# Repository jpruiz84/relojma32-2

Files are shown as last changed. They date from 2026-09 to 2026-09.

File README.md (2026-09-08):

# Reloj MA 32-2 — Electrónica

Repositorio de diseño del **Reloj Multi Alarma MA 32-2** de **Galeras Digital**: un temporizador
programable para timbres escolares construido alrededor de un microcontrolador PIC16F877A.
Contiene el firmware en ensamblador, los esquemáticos y PCB, los planos de la caja metálica,
el manual de usuario, el folleto comercial y los archivos de producción.

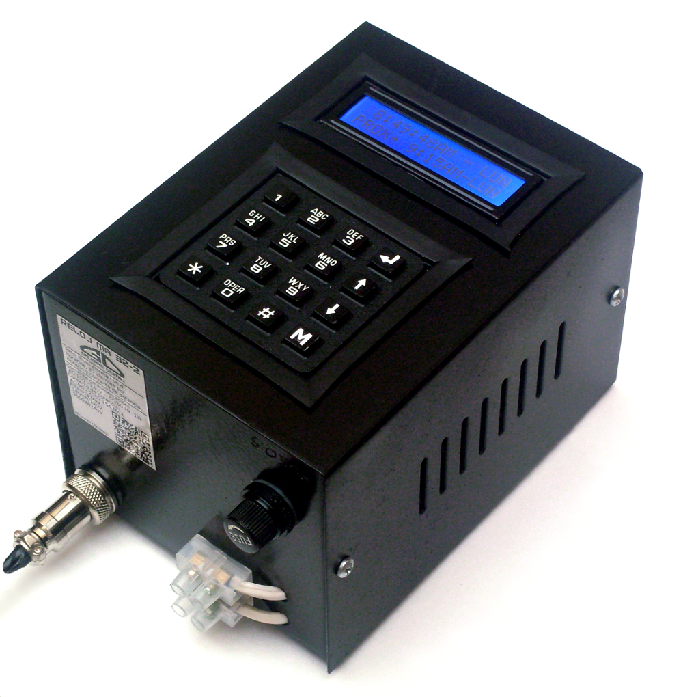
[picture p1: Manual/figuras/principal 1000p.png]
Reloj MA 32-2


## Simulador web 3D

La aplicación en [`simulator/`](simulator/) permite operar el reloj con su teclado original,
programar los cuatro horarios, acelerar el tiempo y retirar la tapa para inspeccionar los
circuitos. Usa el modelo 3D original de ARES, las medidas de la caja, las fotografías y una
implementación funcional basada en el ensamblador.

```bash
cd simulator
npm ci
npm run dev
```

Incluye importación/exportación de EEPROM `.MCH`, protección por contraseña, respaldo de hora,
contacto de potencia, fusible y sonido opcional. Consulte el [README del simulador](simulator/README.md)
y las [notas de fidelidad](simulator/docs/FIDELITY.md) para las fuentes, pruebas, detalles inferidos
y diferencias frente a una emulación del PIC a nivel de instrucciones.

El logotipo del menú LCD reproduce exactamente los 48 bytes de `LCD_DIBLOGORET`: seis
caracteres de 5 × 8 píxeles en las últimas seis posiciones de la primera línea, tanto
en la pantalla 3D como en el panel de controles.

Para generar la versión de producción y ejecutar las pruebas:

```bash
npm run build   # Archivos estáticos en simulator/dist/
npm test       # Pruebas de firmware, EEPROM y bitmap del logotipo
npm run test:e2e # Pruebas de interacción en navegador
```

El [despliegue como servicio](simulator/deploy/README.md) usa HTTPS, renovación automática
del certificado, inicio al arrancar el servidor y acceso mediante un enlace privado
aleatorio. La dirección del servidor y el enlace de acceso se configuran fuera del
repositorio. La guía incluye actualización, reversión y revocación del enlace.

## Descripción del producto

El Reloj MA 32-2 es un dispositivo electrónico con reloj calendario que activa un timbre,
chicharra, alarma u otro equipo similar según un horario programado y durante un tiempo
configurable. Fue diseñado para establecimientos educativos que marcan el cambio de clase con
timbre, de modo que la programación se realiza una sola vez y el equipo se encarga del resto.

Los equipos han estado en funcionamiento en instituciones educativas de la ciudad de Pasto
(Colombia), entre ellas el Colegio Ciudad de Pasto, INEM, Liceo Central de Nariño, Normal
Superior y Heraldo Romero.

### Características principales

| Característica | Detalle |
|---|---|
| Horarios | 4 tipos de horario independientes, asignables a cada día de la semana (o ninguno, OFF) |
| Alarmas | 30 alarmas por horario (120 en total), cada una con estado ON/OFF |
| Tipos de timbrado | 1TC (1 timbre corto), 1TL (1 timbre largo), 2TC (2 cortos), 3TC (3 cortos) |
| Duración de timbres | Duración del timbre corto (TC) y largo (TL) configurables en segundos |
| Contacto de potencia | 15 A máx. a 100–240 VAC (1800 W / 3600 W), protegido con fusible de 15 A |
| Alimentación | 12 VDC, 500 mA máx. (adaptador externo 100–240 VAC, ~1 W) |
| Respaldo de hora | Pila CR2032 para el reloj de tiempo real (~10 años) |
| Memoria | EEPROM interna del PIC; la configuración no se pierde sin energía |
| Pantalla | LCD 16×2 retroiluminado; muestra la hora actual y el próximo timbre |
| Teclado | Matricial 4×4: números 0–9, Enter, ↑, ↓, Menú (M), `*` luz de fondo, `#` timbrado manual |
| Seguridad | Contraseña de 4 dígitos opcional para acceder al menú |
| Interruptor superior | Habilita o inhabilita el timbrado automático (días festivos) |
| Precisión | Basada en el reloj de tiempo real DS1307 con cristal de 32.768 kHz |

### Menú de configuración

Se accede con la tecla **M** y se navega con **↑ / ↓** y **Enter**:

- **Fijar Reloj**: hora, minutos, segundos, AM/PM y día de la semana.
- **Fijar Alarmas**: para cada horario (H1–H4), cada alarma 01–30 con hora, AM/PM, tipo de timbrado y estado ON/OFF.
- **Tipo de Horario**: horario (1–4 u OFF) asignado a cada día de la semana.
- **Contraseña**: activar/desactivar y definir la clave de 4 dígitos.
- **Dura. Timbres**: duración en segundos del timbre corto y del timbre largo.

Si se olvida la contraseña, se retira la pila CR2032 durante al menos 10 segundos: el firmware
detecta el bit CH del DS1307, realiza la carga inicial y deshabilita la contraseña.

El manual de usuario completo está en `Manual/manual.pdf` y el folleto comercial en
`Folleto/folleto_reloj_ma32-2.pdf`.

## Hardware

| Bloque | Componente | Notas |
|---|---|---|
| Microcontrolador | PIC16F877A | Cristal de 4 MHz (oscilador XT), WDT activado, protección de código |
| Reloj de tiempo real | DS1307 | Bus I²C por software (SCL = RA3, SDA = RA4), cristal 32.768 kHz, pila CR2032 |
| Base de tiempo | Salida SQW del DS1307 a 1 Hz | Conectada a RB0/INT; genera la interrupción que actualiza la pantalla |
| Pantalla | LCD 16×2 compatible LM016L | Modo 4 bits en PORTD: RS = RD1, R/W = RD2, E = RD3, datos RD4–RD7 |
| Luz de fondo | Transistor desde RC1 | Se apaga 10 s después de la última tecla |
| Teclado | Matricial hexadecimal 4×4 | Filas en RA0, RB1, RB2 y RB3; columnas en RB4–RB7 con interrupción por cambio de estado |
| Salida de timbre | RC0 → 2N2222 → relé 12 V / 40 A | Contacto protegido con fusible de 15 A |
| Regulación | 7805 | Entrada 12 VDC |
| Caja | Metálica ref. C57 | Planos en `Caja/` |

Los directorios `Circuitos/Potencia prototipo1` y `Circuitos/moc con boton` contienen prototipos
de la etapa de potencia con optotriac MOC30xx, previos a la versión con relé.

## Firmware

### Organización

- `relojma.asm`: programa principal (menús, reloj, comparación y disparo de alarmas).
- `Librerias/`: rutinas reutilizables incluidas desde el programa principal.

| Librería | Función |
|---|---|
| `TECLADO.INC` | Lectura del teclado matricial 4×4 con tabla de conversión |
| `LCD_4BITOPD877.INC` | Control del LCD en modo 4 bits sobre PORTD |
| `RETARDOS.INC` | Retardos calibrados para 4 MHz (de 4 µs a 20 s) |
| `BUS_I2C.INC` | Maestro I²C por software |
| `DS1307.INC` | Lectura/escritura del reloj calendario DS1307 |
| `EEPROM.INC` | Lectura y escritura de la EEPROM interna del PIC |
| `BINAD99.INC` | Conversión binario a BCD (0–99) |
| `CONTRASENA.INC` | Vacía (la lógica de contraseña está en el programa principal) |

Las librerías de teclado, LCD, retardos, I²C y DS1307 provienen del libro
*Microcontrolador PIC16F84. Desarrollo de proyectos* (E. Palacios, F. Remiro y L. López,
Ed. Ra-Ma), adaptadas al PIC16F877A. `BINAD99.INC` procede del proyecto de grado de Juan Pablo
Ruiz Rosero (Ingeniería Electrónica, Universidad de Nariño, 2008).

### Funcionamiento

El bucle principal ejecuta `SLEEP`; todo el trabajo ocurre en la rutina de interrupción:

- **INT (RB0)**: cada flanco de la señal de 1 Hz del DS1307. El firmware alterna el flanco
  activo para despertar cada 500 ms, lee la hora por I²C, refresca la pantalla (con los dos
  puntos fijos en esta revisión), descuenta el temporizador de la luz de fondo y comprueba si la alarma
  más cercana coincide con la hora actual. Si coincide, cierra el contacto según el tipo de
  timbrado y recalcula la siguiente alarma (`COMPALARMAS`).
- **RBIF (RB4–RB7)**: pulsación de tecla. `M` entra al menú (pidiendo contraseña si está
  activa), `#` cierra el contacto mientras se mantiene pulsada y `*` enciende la luz de fondo.

Patrones de timbrado (TC y TL son las duraciones configuradas en segundos):

| Tipo | Secuencia del contacto |
|---|---|
| 1TC | cerrado TC s |
| 1TL | cerrado TL s |
| 2TC | cerrado TC s, pausa 1 s, cerrado TC s |
| 3TC | cerrado TC s, pausa 1 s, cerrado TC s, pausa 1 s, cerrado TC s |

### Mapa de la EEPROM interna (256 bytes)

| Dirección | Contenido |
|---|---|
| `0x02`–`0xF1` | 120 alarmas de 2 bytes. Alarma *N* (1–30) del horario *H* (1–4) en `2 × (N + 30 × (H − 1))` |
| `0xF2`–`0xF8` | Tipo de horario de lunes a domingo (0 = OFF, 1–4) |
| `0xFB` | Duración del timbre corto menos uno (0–15 representa 1–16 segundos) |
| `0xFC` | Duración del timbre largo menos uno (0–15 representa 1–16 segundos) |
| `0xFD` | Bit 0: contraseña habilitada |
| `0xFE`–`0xFF` | Contraseña de 4 dígitos (2 bytes BCD) |

Formato de cada alarma:

- **Byte 0**: bits 7–6 tipo de timbrado (`00` 1TC, `01` 1TL, `10` 2TC, `11` 3TC); bits 5–0 hora en BCD (formato 24 h).
- **Byte 1**: bit 7 estado (1 = ON); bits 6–0 minutos en BCD.

### Memoria de programa

El código ocupa las páginas 0 y 1 del PIC (2675 de 8454 palabras, 31 %). La página 0 contiene el
programa principal, la página 1 (`0x900`) los menús de configuración y `COMPALARMAS`, y en
`0xE01` se ubica el logotipo que se carga en la CGRAM al arrancar y se muestra en el menú. El código comprueba con
directivas `ERROR` que ninguna sección invada la siguiente.

### Compilación

El proyecto se ensambla con **MPLAB IDE 8.x / MPASM** (última compilación con MPASM 5.42 el
28 de septiembre de 2014):

- `relojmaws.mcw`: espacio de trabajo de MPLAB.
- `relojma.mcs`: proyecto de MPLAB.
- `relojma.HEX`: firmware listo para grabar en el PIC16F877A.
- `relojma.cof`, `relojma.lst`, `relojma.map`, `relojma.O`, `relojma.err`: salidas del ensamblador.

Bits de configuración:

```
__CONFIG _CP_ALL & _WDT_ON & _BODEN_ON & _PWRTE_ON & _XT_OSC & _LVP_OFF & _CPD_OFF
```

Los `INCLUDE` usan rutas con barra invertida (`Librerias\...`), por lo que el ensamblado está
pensado para Windows. El archivo `.err` solo contiene mensajes 302/306 (bancos y páginas), sin
errores. La versión mostrada en pantalla por el firmware es `V:06/12`.

### Volcados de EEPROM (`*.MCH`)

Los archivos `.MCH` son exportaciones de la memoria EEPROM desde MPLAB (un byte hexadecimal por
línea) con configuraciones de alarmas reales y de prueba. Sirven para cargar de una vez la
programación de una institución al grabar el PIC:

- `heraldoromero.MCH`, `timbresinem.MCH`: configuraciones de instituciones educativas.
- `alarmaccp.MCH`, `pruebasyccp.MCH`, `alarmas1.MCH`, `memoria1.MCH`: otras configuraciones.
- `prueba30min.MCH`, `pruebaseguida.MCH`: configuraciones de prueba.
- `alarmas1.TXT`, `eeprom.bin`: volcados equivalentes en otros formatos.

## Estructura del repositorio

```
.
├── relojma.asm               Firmware principal (PIC16F877A, ensamblador MPASM)
├── relojma.HEX               Firmware compilado
├── relojmaws.mcw / relojma.mcs   Espacio de trabajo y proyecto de MPLAB
├── relojma.DSN / relojma2.DSN    Esquemático de simulación en Proteus ISIS
├── *.MCH, alarmas1.TXT, eeprom.bin   Volcados de EEPROM con configuraciones de alarmas
├── Librerias/                Librerías en ensamblador (teclado, LCD, I2C, DS1307, EEPROM, retardos)
├── Circuitos/                Esquemáticos y PCB en Proteus (ISIS .DSN / ARES .LYT)
│   ├── PCBMICRO/             Gerbers de la primera placa (febrero de 2009)
│   ├── Version 2/            Placa versión 2 (diciembre de 2013), PDF y modelo 3D (.3DS)
│   ├── Potencia prototipo1.* Prototipo de etapa de potencia con optotriac
│   └── moc con boton.*       Prueba de optotriac MOC30xx con pulsador
├── Caja/                     Planos de la caja metálica
│   ├── frente.dxf, inferior.dxf, conectores.dxf   Cortes y perforaciones (abrir con QCAD)
│   ├── cauchos*.svg, huecos abajosvg.*             Plantillas de cauchos y perforaciones
│   ├── medidas.ods           Cotas en milímetros de LCD, teclado, PCB y conectores
│   ├── especificaciones.svg  Etiqueta de especificaciones (versión antigua, 32 alarmas / 2 horarios)
│   ├── Teclado/              Marco de teclas y flechas (CorelDRAW, SVG)
│   └── Antiguas medidas/     Planos de la versión anterior
├── Manual/                   Manual de usuario en LaTeX (manual.tex → manual.pdf)
│   ├── figuras/              Figuras EPS/SVG/PDF del manual
│   ├── fuentes/              Tipografía de la pantalla LCD
│   └── Antiguo/              Versión anterior del manual
├── Folleto/                  Folleto comercial en LaTeX (folleto.tex → folleto_reloj_ma32-2.pdf)
│   ├── partes/               Imágenes del folleto
│   ├── Fotos/                Fotografías del equipo (junio de 2012)
│   └── resolucion.sh         Compresión del PDF con Ghostscript
├── Otros/
│   ├── relojma_conilcd2.asm  Variante del firmware que reinicializa el LCD periódicamente
│   ├── etiqueta.svg, etiquetas mosaico.*   Etiqueta del producto y hoja para imprimir
│   └── Materiales Fabricación.ods          Lista de materiales con costos y proveedores
└── Pagina/                   Imágenes para la página web
```

## Documentación

El manual y el folleto están escritos en LaTeX con figuras EPS, por lo que se compilan con la
cadena `latex → dvips → ps2pdf`:

```bash
cd Manual
latex manual.tex && latex manual.tex   # dos pasadas para el índice
dvips manual.dvi -o manual.ps
ps2pdf manual.ps manual.pdf
```

El folleto se compila de la misma forma dentro de `Folleto/`. El script `Folleto/resolucion.sh`
reduce el tamaño del PDF con Ghostscript.

## Herramientas utilizadas

| Área | Herramienta |
|---|---|
| Firmware | MPLAB IDE 8.x, MPASM 5.42 |
| Esquemáticos y PCB | Proteus ISIS / ARES (archivos `.DSN`, `.LYT`, Gerber RS-274X) |
| Caja | QCAD (DXF), Inkscape (SVG), CorelDRAW (CDR), LibreOffice Calc (ODS) |
| Documentación | LaTeX (KOMA-Script `scrbook`, babel español), dvips, Ghostscript |

## Historia del diseño

- **2008**: primeras compras de componentes y pruebas con optotriacs y contactores.
- **Febrero de 2009**: Gerbers de la primera placa, fabricada por PCB Microcircuitos.
- **2009**: volcados de EEPROM de las primeras instalaciones en colegios de Pasto.
- **Junio de 2012**: versión de firmware `06/12` (30 alarmas × 4 horarios), fotografías y folleto.
- **Diciembre de 2013**: placa versión 2 con modelo 3D.
- **Septiembre/octubre de 2014**: última compilación del firmware y manual versión 3.03.

El nombre **MA 32-2** proviene de la versión original del producto (32 alarmas, doble horario),
como indica la etiqueta antigua en `Caja/especificaciones.svg`. La versión actual del firmware
ofrece 4 horarios de 30 alarmas cada uno.

## Licencia

Este proyecto se distribuye bajo la licencia **MIT**. Consulte el archivo [`LICENSE`](LICENSE)
para el texto completo.

Las librerías `TECLADO.INC`, `LCD_4BITOPD877.INC`, `RETARDOS.INC`, `BUS_I2C.INC` y
`DS1307.INC` derivan del libro *Microcontrolador PIC16F84. Desarrollo de proyectos*
(E. Palacios, F. Remiro y L. López, Ed. Ra-Ma) y conservan los derechos de sus autores
originales.

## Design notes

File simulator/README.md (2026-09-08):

# Reloj MA 32-2 · Interactive lab

A local, static web application that reconstructs the Galeras Digital school-bell controller from the firmware and manufacturing archive in this repository. React renders the lab controls, Three.js renders the physical device, and a deterministic TypeScript state machine reproduces the firmware's defined user-facing behavior.

## Run

Requires Node.js 22.12+ and npm.

```sh
cd simulator
npm ci
npm run dev
```

Open the printed localhost address (normally http://localhost:5173). There is no backend, account, cloud service, or runtime CDN. A browser with WebGL 2 is required for 3D rendering. If WebGL is unavailable, the accessible keypad and schedule controls remain usable.

```sh
npm run build    # TypeScript checks and deployable static files in dist/
npm run preview  # Serve the production build locally
npm test         # Deterministic firmware/EEPROM tests
npm run test:e2e # Chrome/Playwright browser tests
```

The browser tests use `/usr/bin/google-chrome` when present. Alternatively set `CHROME_PATH` to your browser executable or run `npx playwright install chromium`. The tests enable software WebGL, allowing CI to verify the actual native PCB loader without a GPU.

## Use the lab

For the hosted service, private-link access, updates and link rotation, see
[deployment instructions](deploy/README.md). The deployment secret is stored only
on the server.

- **Operate:** use the 3D front-panel keys or the accessible keypad. `M` opens the original Spanish menus; `↑`/`↓` selects; Enter confirms. The physical keyboard also accepts digits, arrows, Enter, M/Escape, `*` and `#` when a form control is not focused. Hold `#` for manual output; release to stop.
- **Schedules:** edit any of the 30 slots in each of four schedules, assign schedules or OFF to each weekday, and set TC/TL to 1–16 seconds. Password-protected configuration can be unlocked through the original keypad. EEPROM import/export is an explicit lab programming tool and can overwrite password bytes.
- **Electronics:** remove the cover, explode the PCB from its mounts, toggle labels, inspect components and their real net connections, or disconnect the CR2032/fuse.
- **Source archive:** inspect all 15 supplied raster images, original manual, source assembly, PCB artwork, exported schematic and five vector drawings.
- **Virtual time:** pause, step 500 ms, set weekday/time, run at 1×/10×/60×/600×, or jump to five seconds before the next alarm. Sound is optional and synthesized from the contact state.

The first launch loads a **demonstration** school schedule at Monday 06:59:50 with a 07:00 bell. It is not presented as a factory EEPROM image. Archived captures are available by their original filenames. Partial `.MCH` captures overwrite only their supplied bytes; the remainder stays intact. Export before replacing a configuration you want to keep.

EEPROM and RTC state persist in this browser's `localStorage`. Reopening advances the backed-up RTC by real elapsed time; it does not replay alarms while the browser was closed. The simulation affects only the virtual device.

## Reconstruction and fidelity

The circuit uses the **original 105-mesh `Circuitos/Version 2/modelo.3DS`**, including copper artwork and components. The 28 component values/placements and 47 nets are extracted from `.SDF` and `.EDF`. The 113.1 × 154.8 mm front plate and display/keypad apertures use `Caja/medidas.ods`; product and installation photos guide the black enclosure, vents, keypad, display colors and connectors.

The later 2013 PCB and 2012 exterior photos represent different archive revisions. Enclosure depth, assembly offsets, external relay geometry, materials and cable routing are reconstructed. The original PCB's placeholder colors are replaced with component-appropriate materials while preserving the source mesh vertices. Ribbon ends on the lifted cover are illustrative, not a manufacturing harness reconstruction.

This is a **functional firmware port, not instruction-cycle or analog electrical emulation**. It covers menus, packed EEPROM, scheduling, bell pulses, manual actuation, menu blocking, password protection and power/backup behavior. It deliberately preserves relevant alarm-search quirks and guards undefined inputs. [Fidelity notes](docs/FIDELITY.md) explain source mappings, conflicts and limits in detail; the same material is summarized in the app's guide.

Three.js integrations follow the official [TDSLoader](https://threejs.org/docs/pages/TDSLoader.html) and [OrbitControls](https://threejs.org/docs/pages/OrbitControls.html) documentation.

## Rebuild source assets

Generated browser assets are committed so running the app does not require Python. To regenerate after changing archive files:

```sh
# Python 3 with Pillow and Ghostscript (gs) installed
npm run assets
```

`prepare_assets.py` copies the native board, LCD font and original documents, renders the exact white underside label from `Manual/figuras/inferior1.eps`, makes web-sized photo copies, and generates `public/assets/design.json`. This manifest preserves original relative filenames and the board's SHA-256. It also includes the 98 routed paths from the ARES session file. The original archive files are left untouched.

## Files

| File | Responsibility |
| --- | --- |
| `src/engine.ts` | Time, firmware menu state, alarm selection, relay pulses, EEPROM |
| `src/scene.ts` | Native PCB loading, measured enclosure, picking and camera |
| `src/App.tsx` | Operate, schedules, circuit inspector, sources and persistence |
| `src/design.ts` | Source-backed component explanations |
| `src/engine.test.ts` | Firmware, memory and power regression tests |
| `tests/lab.spec.ts` | Actual browser, 3D, keyboard and mobile workflows |
| `scripts/prepare_assets.py` | Reproducible asset extraction and provenance |

The application follows the repository's MIT license; original reference files retain their existing notices.

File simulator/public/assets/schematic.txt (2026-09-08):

ISIS SCHEMATIC DESCRIPTION FORMAT 6.1
=====================================
Design:   D:\Dropbox\Galeras Digital\Reloj MA 32-2\Electronica RelojMa\Circuitos\Version 2\placa real.DSN
Doc. no.: <NONE>
Revision: <NONE>
Author:   <NONE>
Created:  07/12/08
Modified: 18/12/13

*PROPERTIES,0    

*MODELDEFS,0    

*PARTLIST,28   
BAT1,CELL,3V,EID=1D,PACKAGE=BAT2032
C1,AVX0603NPO22P,22p,CODE="Farnell 498-543",EID=1F,PACKAGE=CAP10,PINSWAP="1,2"
C2,AVX0603NPO22P,22p,CODE="Farnell 498-543",EID=20,PACKAGE=CAP10,PINSWAP="1,2"
C3,PCELECT1000U16V,2000u,CODE="Maplin VH50E",EID=23,PACKAGE=ELEC-RAD20
C4,PCELECT1000U16V,2000u,CODE="Maplin VH50E",EID=26,PACKAGE=ELEC-RAD20
C5,PHYC1206NPO100P,100p,CODE="Farnell 360-6077",EID=27,PACKAGE=CAP10,PINSWAP="1,2"
C6,PHYC1206NPO100P,100p,CODE="Farnell 360-6077",EID=28,PACKAGE=CAP10,PINSWAP="1,2"
D1,1N4006,1N4006,EID=25,PACKAGE=DO41
D2,1N5232B,1N5232B,BV=5.6,EID=3C,IBV=20.0m,PACKAGE=DO35
D3,1N5243B,1N5243B,BV=13.0,EID=3A,IBV=9.5m,PACKAGE=DO35
J1,CONN-H12,CONN-H12,EID=18,PACKAGE=CONN-SIL12
J2,CONN-H2,CONN-H2,EID=21,PACKAGE=CONN-SIL2
J3,CONN-H2,CONN-H2,EID=3B,PACKAGE=CONN-SIL2
J5,CONN-H2,CONN-H2,EID=34,PACKAGE=CONN-SIL2
Q1,2N2222,2N2222,EID=1A,PACKAGE=TO92-100
Q2,2N2222,2N2222,EID=37,PACKAGE=TO92-100
R1,MINRES1K,1k,CODE=M1k,EID=1B,PACKAGE=RES40,PINSWAP="1,2",PRIMTYPE=RESISTOR
R4,MINRES220R,1K,CODE=M220R,EID=31,PACKAGE=RES40,PINSWAP="1,2",PRIMTYPE=RESISTOR
R5,MINRES1K,1k,CODE=M1k,EID=33,PACKAGE=RES40,PINSWAP="1,2",PRIMTYPE=RESISTOR
R6,MINRES4K7,4k7,CODE=M4K7,EID=14,PACKAGE=RES40,PINSWAP="1,2",PRIMTYPE=RESISTOR
R7,MINRES4K7,4k7,CODE=M4K7,EID=15,PACKAGE=RES40,PINSWAP="1,2",PRIMTYPE=RESISTOR
RV1,POT,POT,EID=19,PACKAGE=PRE-SQ4,STATE=5
TECLADO,KEYPAD-HEX-SANYO,TECLADO,A1="SQUARE,0300,-300,300",A2="SQUARE,0700,-300,300",A3="SQUARE,1100,-300,300",A4="SQUARE,1500,-300,300",B1="SQUARE,0300,-700,300",B2="SQUARE,0700,-700,300",B3="SQUARE,1100,-700,300",B4="SQUARE,1500,-700,300",C1="SQUARE,0300,-1100,300",C2="SQUARE,0700,-1100,300",C3="SQUARE,1100,-1100,300",C4="SQUARE,1500,-1100,300",D1="SQUARE,0300,-1500,300",D2="SQUARE,0700,-1500,300",D3="SQUARE,1100,-1500,300",D4="SQUARE,1500,-1500,300",EID=B,MODDLL=KEYPAD,PACKAGE=CONN-SIL8
U1,DS1307,DS1307,AUTOINIT=0,EID=10,ITFMOD=DS1307ITF,PACKAGE=DIL08,TRACE=1
U2,PIC16F877A,PIC16F877A,ADC_ACQUISITION_TIME=20u,ADC_RCCLOCK_PERIOD=4u,ADC_SAMPLE_DELAY=100n,CFGWORD=0x3FFB,CLOCK=4MHz,DBG_ADC_BREAK=0,DBG_GENERATE_CLKOUT=0,DBG_RANDOM_DMEM=0,DBG_RANDOM_PMEM=0,DBG_STARTUP_DELAY=0,DBG_WAKEUP_DELAY=0,EID=17,EPR_WRITECODE_DELAY=10m,EPR_WRITEDATA_DELAY=10m,ITFMOD=PIC,MODDATA="256,255",MODDLL=PIC16,PACKAGE=DIL40,PORTTDHL=0,PORTTDLH=0,PROGRAM=relojma.HEX,TRACE_DEFAULT=1,WDT_PERIOD=18m
U3,7805,7805,EID=24,PACKAGE=REG7805DISP
X1,CRYSTAL,CRYSTAL,EID=11,FREQ=32.768KHz,PACKAGE=CAP10
X2,CRYSTAL,CRYSTAL,EID=1E,FREQ=32.768KHz,PACKAGE=XTAL18

*NETLIST,47   
#00025,2
U1,IP,3
BAT1,PS,1

#00026,2
U1,IP,1
X1,PS,2

#00027,2
U1,IP,2
X1,PS,1

#00039,1
U2,IO,8

#00040,1
U2,IO,9

#00041,1
U2,IO,10

#00042,3
U2,IP,13
X2,PS,2
C2,PS,1

#00043,3
U2,OP,14
X2,PS,1
C1,PS,1

#00045,1
U2,IO,17

#00046,1
U2,IO,18

#00055,1
U2,IO,26

#00056,1
U2,IO,25

#00057,1
U2,IO,24

#00058,1
U2,IO,23

#00063,2
J1,PS,3
RV1,PS,3

#00065,2
J1,PS,12
Q1,PS,3

#00066,2
Q1,PS,2
R1,PS,1

#00075,2
R4,PS,1
J5,PS,1

#00076,2
R4,PS,2
Q2,PS,2

#00077,3
Q2,PS,3
D3,PS,A
J3,PS,1

RD0,2
RD0,GT
U2,IO,19

RD1,3
RD1,GT
J1,PS,4
U2,IO,20

RD3,3
RD3,GT
J1,PS,6
U2,IO,22

RD7,3
RD7,GT
J1,PS,10
U2,IO,30

RD6,3
RD6,GT
J1,PS,9
U2,IO,29

RD5,3
RD5,GT
J1,PS,8
U2,IO,28

RD4,3
RD4,GT
J1,PS,7
U2,IO,27

RA0,3
RA0,GT
U2,IO,2
TECLADO,PS,5

RA1,2
RA1,GT
U2,IO,3

RA2,2
RA2,GT
U2,IO,4

RA4,4
RA4,GT
U2,IO,6
U1,IO,5
R7,PS,1

RA5,2
RA5,GT
U2,IO,7

RB7,3
RB7,GT
U2,IO,40
TECLADO,PS,4

RB6,3
RB6,GT
U2,IO,39
TECLADO,PS,3

RB5,3
RB5,GT
U2,IO,38
TECLADO,PS,2

RB4,3
RB4,GT
U2,IO,37
TECLADO,PS,1

RB3,3
RB3,GT
U2,IO,36
TECLADO,PS,8

RB2,3
RB2,GT
U2,IO,35
TECLADO,PS,7

RB1,3
RB1,GT
U2,IO,34
TECLADO,PS,6

RB0,4
RB0,GT
U2,IO,33
U1,OP,7
R5,PS,1

RA3,4
RA3,GT
U2,IO,5
U1,IP,6
R6,PS,1

RD2,3
RD2,GT
J1,PS,5
U2,IO,21

RC1,3
RC1,GT
R1,PS,2
U2,IO,16

RC0,3
RC0,GT
J5,PS,2
U2,IO,15

12V,7
12V,GT
D3,PS,K
J3,PS,2
J2,PS,2
C3,PS,+
U3,IP,1
D1,PS,K

GND,20,CLASS=POWER
GND,PR
VSS,PT
U2,PP,12
U2,PP,31
Q2,PS,1
J2,PS,1
C3,PS,-
U3,IP,2
C4,PS,-
C6,PS,1
C5,PS,1
D2,PS,A
D1,PS,A
C1,PS,2
C2,PS,2
BAT1,PS,2
Q1,PS,1
U1,PP,4
J1,PS,1
RV1,PS,1

VCC/VDD,18,CLASS=POWER
VCC,PT
VDD,PT
VCC/VDD,PR
U1,PP,8
U3,IP,3
C6,PS,2
C5,PS,2
C4,PS,+
D2,PS,K
U2,PP,11
U2,PP,32
R7,PS,2
R6,PS,2
R5,PS,2
J1,PS,2
J1,PS,11
RV1,PS,2
U2,IP,1

*GATES,0

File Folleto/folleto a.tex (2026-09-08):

\documentclass[8pt,notitlepage,openany]{scrbook}
\usepackage{anysize}
\paperwidth = 13.95cm
\paperheight = 21.6cm
\marginsize{1.5cm}{1.5cm}{0.3cm}{0.3cm} %\marginsize{izq}{der}{sup}{inf }

\usepackage{bera}		% Define el tipo de letra
\usepackage{arev}

%\oddsidemargin = 4cm
%\evensidemargin = 2cm
%\usepackage[left=6.8cm,top=6cm,right=0cm]{geometry} 
%left 0=2.8,
%\documentclass[bsc,draft,singlespacing]{csthesis}
%\documentclass[bsc,doublespacing]{csthesis}
      
\usepackage[spanish]{babel}     % Idioma de Capítulos y demás
\usepackage[T1]{fontenc} 
\usepackage[utf8x]{inputenc}

\usepackage{verbatim}
\usepackage{moreverb}
\let\verbatiminput=\verbatimtabinput
\def\verbatimtabsize{8} 
\usepackage{hyperref}

\usepackage{multicol}

\usepackage{mathcomp}
\usepackage{latexsym}
\usepackage{pifont}
\usepackage{amsfonts}
\usepackage{amssymb}
\usepackage{wasysym}
\usepackage{colortbl}
\usepackage{multicol} 
\usepackage{booktabs}

\usepackage{graphicx}

\setlength{\parindent}{0cm}
\setlength{\parskip}{0.3cm}

\begin{document}
\pagestyle{empty}

%\begin{center}
\hspace{-0.6cm}
 % tapa.eps: 1307x2072 pixel, 300dpi, 11.07x17.54 cm, bb=0 0 314 497
%\end{center}

La empresa \textbf{GALERAS DIGITAL}, pone a su disposición el Reloj Multi Alarma MA 32-2.

El Reloj Multi Alarma MA 32-2 es un dispositivo electrónico de alta calidad y precisión que tiene como función principal la activación o ejecución de un timbre, chicharra, alarma u otro equipo similar, de acuerdo a un horario determinado y por un espacio de tiempo programado.

Este equipo fue diseñado especialmente para los establecimientos educativos que marcan el cambio de clase con timbre o chicharra.

\begin{center}
 
 % timbre.eps: 824x594 pixel, 300dpi, 6.98x5.03 cm, bb=0 0 198 143
\end{center}

\textbf{Ventajas:}

\begin{itemize}
\item La precisión en el timbre para el cambio de hora, es de gran importancia para toda la comunidad educativa, pero especialmente para el docente quien podrá programar sus actividades de clase con la plena seguridad de que el timbre de cambio de hora sonará con una precisión de segundos.

\item La labor diaria y constante del toque del timbre quedará relegada por completo, ya que el Reloj MA 32-2 se programa sencillamente por una sola vez y no requiere de ninguna otra operación.

\item El funcionario encargado de esta rutinaria tarea quedará libre para dedicar su atención a labores mas productivas para la institución.
\end{itemize}

\textbf{Características:}

\begin{itemize}
\item \textbf{Diferenciación de horarios:} El Reloj MA 32-2 permite programar cuatro horarios distintos  fácilmente intercambiables en diferentes días, cada uno hasta con hasta 30 alarmas.

\item \textbf{Fácil Manejo:} Gracias a su teclado numérico y pantalla LCD, su programación es muy sencilla y se realiza por una sola vez, esta no se borrará aunque se suspenda el fluido eléctrico.

\item \textbf{Pila de respaldo:} El Reloj MA 32-2 cuenta con una pila de respaldo la cual permite al sistema mantener la hora en caso de cortes en el fluido eléctrico. La pila usada, CR2032, tiene una duración de 10 años.

\item \textbf{Seguridad:} El Reloj MA 32-2 posee un sistema de seguridad que solicita una clave o contraseña, para evitar que personas no autorizadas accedan o modifiquen la programación.

\item \textbf{Calidad:} El Reloj MA 32-2 está elaborado con materiales de altísima calidad lo que garantiza un funcionamiento preciso e ininterrumpido durante muchos años.

\item \textbf{Experiencia:} Estos equipos han estado funcionando mas de 3 años consecutivos en las principales instituciones educativas de la ciudad de Pasto, tales como: 

\begin{multicols}{2}

\vspace{-0.2cm}\subitem - Colegio Ciudad de Pasto 
\vspace{-0.2cm}\subitem - INEM
\vspace{-0.2cm}\subitem - Liceo Central de Nariño
\vspace{-0.2cm}\subitem - Libertad
\vspace{-0.2cm}\subitem - Bethlemitas
\vspace{-0.2cm}\subitem - Normal Superior
\vspace{-0.2cm}\subitem - Heraldo Romero
\vspace{-0.2cm}\subitem - LEMO
\vspace{-0.2cm}\subitem - Britanico
\vspace{-0.2cm}\subitem - SUCRE
\vspace{-0.2cm}\subitem - INSUR
\end{multicols}

\end{itemize}

\vspace{-0.3cm}
\begin{center}
 
\end{center}

\begin{tabbing}
\hspace{7cm}\=\kill
\textbf{Costo 1 equipo c/u} \> \$849.000\\ 
\textbf{Precio especial para instituciones} \> \\
\textbf{en convenio con la asociación de} \> \\
\textbf{Rectores de Departamento de Nariño:} \> \$650.000
\end{tabbing} 

\vspace{-0.7cm}
\begin{flushright}
\textbf{Garantía por un año}
\end{flushright}

\vspace{0.2cm}

\begin{small}
\textbf{Contactenos:}\\
\\
\textbf{Ventas y soporte técnico:} \\
\hspace*{0.3cm} - Juan Pablo Ruiz: 301 323 4324 \\
\hspace*{0.3cm} - Ana Cristina Delgado: 317 260 0591 y 312 764 1311\\
\\
\textbf{Pagina web:} https://sites.google.com/site/galerasdigital\\
\textbf{Correo electrónico:} galerasdigital@gmail.com\\

\end{small}

\newpage
\ \\
\vspace{5cm}
\begin{center}
 
 % tapaf.eps: 1111x654 pixel, 300dpi, 9.41x5.54 cm, bb=0 0 267 157
\end{center}
\vspace{3cm}

\end{document}

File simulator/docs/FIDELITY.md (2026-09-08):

# Source mapping and reconstruction limits

This document distinguishes source-derived behavior and geometry from assumptions. The app is a functional reconstruction of the final `relojma.asm` (firmware version `06/12`, last assembled September 2014), using the later production PCB export and the available exterior photographs. It does not execute the PIC HEX file, simulate electrical voltages or assert unseen mechanical details as measured facts.

## Firmware behavior

The menu logo uses all 48 bytes from `LCD_DIBLOGORET` as six 5 × 8 CGRAM
characters. `ITECLADO1` writes codes 0–5 at zero-based columns 10–15 of the
first row. Both the 3D LCD texture and the control-panel display render these
same pixels directly; the logo does not depend on a font or substitute text.

| Feature | Original routine / resource | Implementation |
| --- | --- | --- |
| 16-key layout | `Librerias/TECLADO.INC`, `Tecl_ConvierteOrdenEnHex`; `TARRIBA`, `TABAJO`, `TENTER`, `TMENU` | Rows `1 2 3 Enter`, `4 5 6 ↑`, `7 8 9 ↓`, `* 0 # M`. ↓ increments; ↑ decrements, with wraparound. |
| LCD | `ARELOJ`, `MENDIA`, `MRINGON`, `MRINGOFF` | Two padded/truncated 16-character rows. 12-hour time, Spanish weekday, `PROX` arrow and next bell. During manual ringing the LCD is cleared; automatic sequences preserve the last time row. |
| Clock setting | `FIJARRELOJ` through `FIJARDIASEM` | Six digits, AM/PM toggle, weekday, commit. Noon/midnight conversions reproduce valid 12-hour behavior. |
| Alarm setting | `FIJARALARMAS`, `FIJARUNAALARMA` | H1–H4, slots 01–30, four time digits, AM/PM, four patterns, ON/OFF. Writes on final confirmation. |
| Week mapping | `TIPOHORARIO`, `FIJARTHORARIODIA` | EEPROM `0xF2`–`0xF8`, Monday–Sunday. Zero is OFF, 1–4 selects a schedule. |
| Packed alarms | `FIJARUNAALARMAFIN` | Address `2 × (slot + 30 × (schedule−1))`, with one-based slot/schedule. Hour BCD in bits 5–0; type in bits 7–6; minute BCD in bits 6–0 of the next byte; ON in bit 7. |
| Durations | `DEFDURATIMBRES`; `RETARDOS.INC`, `Retardo_wseg` | Duration is **(EEPROM byte & 0x0F) + 1 seconds**, not the raw byte. `0xFB` stores TC; `0xFC` stores TL. The UI wraps 1–16 seconds. |
| Pulse sequences | `TIMBRAR1TC`, `TIMBRAR1TL`, `TIMBRAR2TC`, `TIMBRAR3TC` | One TC, one TL, two TC or three TC. Exactly 1 s low between short pulses; an additional 1 s low recovery occurs in `TESTEARALARMAFIN`. |
| Manual bell | `ITECLADO` | # raises RC0 until release. Key repeats do not restart it. Release, lost focus and power removal cannot leave a stuck manual contact in the browser. |
| Next alarm | `COMPALARMAS` | Port of unsigned BCD comparisons, current-minute exclusion, first-slot tie resolution, one-hour retry and day traversal. The absolute due time serves as the browser equivalent of occurrence/latch tracking so a weekly recurrence does not retrigger in the same minute. |
| Blocking | Interrupt routine, `ITECLADO2`, blocking delay calls | RTC keeps advancing, but normal alarm checks and idle backlight countdown stop during menus and bell sequences. Missed alarms are not replayed. |
| Password | `DEFCONTRASENA`, `Teclado_LeeHexww` | Four decimal digits, repeated confirmation, BCD bytes `0xFE/0xFF`, enable bit at `0xFD`. Entry has approximately 5.1 s overall timeout (255 × 20 ms), not a separate timeout per digit. |
| Backlight | `TIEMPOLCD = 20`, `CONTLEDLCD`, `PINLEDLCD` | Any key wakes it. Idle operation times it out after 20 half-second ticks; it remains illuminated during blocking menus and pulse execution. |
| Backup recovery | `INICIO`, `DS1307_CargaInicial`, manual password recovery | Both power sources absent for 10 simulated seconds mark the RTC as lost. On main-power restoration: Monday 00:00:00, password disabled, EEPROM alarm data retained. |

## Relevant source quirks and safeguards

1. **LCD colons do not blink in this revision.** `ARELOJ` toggles the AMPM bit, but both literal branches load `':'`. The simulation therefore keeps colons steady, despite the comment and older README description.
2. **Recomputation excludes the current hour/minute.** A bell already selected before its minute will fire, but setting time or leaving a menu at that exact minute selects a later occurrence.
3. **The comparison sum is binary arithmetic on BCD differences.** `ADDWF HORADIF,W` skips any candidate whose hour and minute differences sum to zero modulo 256, not solely an equal timestamp. For example, an alarm at 11:31 is initially skipped from 10:32. This behavior is tested.
4. **Future midnight can be skipped.** The source resets the scan time to 00:00 when traversing days, and its equality exclusion skips that day's 00:00 candidate. This behavior is retained and documented rather than silently presented as a conventional modern scheduler.
5. **Corrupt memory is bounded.** Invalid active BCD timestamps and invalid day schedule IDs are retained in the imported raw EEPROM but not executed. The selector has a bounded search instead of reproducing indefinite loops or watchdog resets.
6. **Defined time-input range is guarded.** The assembly accepts hour digits up to `19` and permits `00` in a 12-hour editor. These are undefined/unintended inputs; the web editor accepts 01–12 (or 00–23 in the explicit lab editor) and valid minutes/seconds.
7. **Backlight counters saturate at zero.** The model expresses the intended 10-second timeout, rather than exposing the MCU counter's later unsigned underflow while the backlight is already off. Sub-second key-scan delays, the minimum ~100 ms manual delay, register banks, WDT reset timing and interrupt instruction latency are not emulated.
8. **Decimal password input.** Non-numeric keys during entry are ignored; the firmware's hexadecimal-key arithmetic in password entry is not treated as a supported feature. Raw EEPROM import/export still preserves every byte.
9. **RTC display scope.** The app models time and weekday because those are the fields exposed by the product UI. DS1307 calendar date/month/year registers, oscillator analog drift, battery discharge and undefined CH startup contents are not an electrical simulation.
10. **EEPROM programming is a lab capability.** Archive import and export operate directly on memory, including password bytes, like MPLAB programming. They are not additional physical keypad features. The initial demonstration schedule is explicitly distinct from archived memory and unknown factory defaults.
11. **Closed browser behavior.** Browser persistence advances the backed-up RTC by real elapsed time on reopen (bounded to one year for corrupt-clock resilience). No software running solely in an ordinary web tab can reproduce an independently powered physical controller's audible output after the tab is closed. The simulator does not replay past bells.

## Electrical source and conflicts

`Circuitos/Version 2/placa real.SDF` is the readable ISIS export: 28 parts and 47 nets. The `.EDF` supplies exact footprint anchors and rotations. `.ses` supplies 98 routed paths. `placa real.PDF` is **PCB copper/silkscreen artwork**, not a circuit schematic sheet. The browser offers that artwork and the actual schematic netlist separately.

- PIC U2: 40-pin PIC16F877A, 4 MHz oscillator, EEPROM inside the PIC.
- RTC U1: DS1307, X1 = 32.768 kHz, BAT1 = 3 V CR2032, SQW to RB0, SDA = RA4 and SCL = RA3.
- U3: 7805, 12 V input, 5 V logic output.
- Q1/R1: RC1-controlled LCD backlight through J1.
- Q2/R4/J3: external 12 V relay driver.
- **J5 is a series link from RC0 to R4 and Q2**, so the model treats the top switch as a physical inhibit for both programmed and manual output. Firmware never reads a switch input. `RING!!` and RC0 can therefore be active with the physical contact open. This follows the schematic even though the panel/manual calls it an automatic-bell switch.
- The manufacturing BOM specifies a **12 V / 40 A relay**, while the external usable contact is protected/rated at **15 A** by the fuse and manual. The UI does not confuse the relay's standalone rating with the protected load rating.
- SDF C3/C4 say **2000 µF**; the BOM says **1000 µF / 16 V**. Inspection retains the SDF value, with this conflict documented. No analog filtering behavior is inferred.
- SDF X2's `FREQ` property says **32.768 kHz**, while the PIC `CLOCK=4MHz`, XT configuration and manufacturing BOM identify the PIC crystal as **4 MHz**. The simulator uses 4 MHz for the PIC description and flags the mismatch in its inspector.
- Older optotriac/MOC experiments in `Circuitos/` are prototypes, not simultaneously installed parts. They are not added to the later relay-based assembly.

## Geometry and imagery

| Element | Evidence | Fidelity |
| --- | --- | --- |
| PCB and component bodies | `Circuitos/Version 2/modelo.3DS` | Original 105-mesh vertices and topology, including copper/silkscreen artwork; source coordinates are centimetres. Material appearance is refined. |
| Component identities and positions | `placa real.SDF`, `placa real.EDF` | Source part values and mm placement anchors. Click targets associate the native objects with source components. |
| Front plate | `Caja/medidas.ods`, `Caja/frente.dxf` | 113.1 × 154.8 mm. |
| LCD/frame | Same measurements; `Manual/figuras/frente1.svg` | LCD 71.1 mm wide; revised opening height 26.9 mm; frame approximately 76.5 × 29.4 mm. The center comes from iLCD/fLCD. |
| Keypad/frame | Same measurements; keypad SVG and photos | Keypad 59.6 × 56.7 mm; frame approximately 65 × 62.1 mm; layout/legends from manual and product photo. |
| Enclosure depth | Connector panel `110.6 × 99.6` in measurements; product perspectives | Approximately 99.6 mm, inferred as enclosure depth from panel dimensions. Not independently measured. |
| Bottom power input, fuse and terminal block | `Caja/conectores.dxf`, dimensions spreadsheet, underside drawing and product photo | Layout follows `Manual/figuras/inferior1.eps`: three-contact input at lower left, fuse at upper right, four-screw terminal block and looped leads at lower right. Depths and material finishes are reconstructed. |
| Cover fold, vents, screws, rocker | Product views, installed views and top drawing | Reconstructed geometry. Wall thickness, exact vent dimensions and fastener head shape are estimates. |
| Relay, internal cables and assembly offsets | BOM, hole locations, netlist and exterior mounting clues | Functional locations and plausible cable routes, not an observed interior photograph. Source files do not supply a complete as-built harness or relay mesh. |
| LCD appearance | Blue product photo and green installed units; bundled `LCD Display Grid.ttf` | Selectable color; shared live content between the 3D texture and accessible LCD. All 48 CGRAM bytes from `LCD_DIBLOGORET` are rendered directly in both displays. |
| Bell sound | No original sound recording supplied | Optional synthesized indication controlled by the simulated protected contact. |

The tall white underside label is rendered directly from `Manual/figuras/inferior1.eps`
into `assets/underside-label.png`, preserving the original logo, embedded typefaces,
specifications, QR code and “HECHO EN COLOMBIA”. It sits at the upper left of the
connector panel in the manual’s orientation. Its approximately 30 × 40 mm size and
placement are scaled from the drawing, rather than independently measured. The
printed ratings are historical artwork and are reproduced without editing.

All 15 raster images under `Pagina/`, `Manual/figuras/`, `Folleto/partes/`, and `Folleto/Fotos/` are indexed and available in the app, including duplicates, signatures, QR artwork and the brochure cover. Not every image supplies geometry: installation photos guide orientation and green LCD appearance; marketing graphics remain references rather than fictitious device surfaces. Five vector diagrams are also linked. The native model is copied byte-for-byte and its SHA-256 is recorded in `design.json`.

## Verification

The deterministic test suite checks the EEPROM boundary addresses and all eight captured memory files, preserved partial imports, BCD quirks, weekday rollover, duplicate times, all four pulse patterns, accelerated playback, manual-release behavior, J5 and fuse gating, every keypad menu, password confirmation/timeouts, power interruption and RTC reset.

The Playwright suite exercises the running React/Three.js application, including actual 3D front-panel picking, opening/exploding the cover, inspecting a source net, physical-keyboard input, schedule persistence through reload, imported/exported captures, timed bell actuation, password recovery, a 390 px mobile viewport and dialog focus containment. Manual screenshot inspection covers assembled, open and mobile views.

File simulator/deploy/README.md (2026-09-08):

# Private-link deployment

The simulator can run on your server under `/opt/reloj-ma`, managed by
`reloj-ma.service`. The service starts a pinned Caddy Docker image; Docker restarts
the container after a crash and systemd starts the service at boot. Only ports
80 and 443 are published. Application files are mounted read-only.

Keep the server address and private link outside Git. Set `DEPLOY_HOST` in your
local shell to your SSH destination (user and hostname), then retrieve the link
over SSH:

```sh
ssh "${DEPLOY_HOST:?Set DEPLOY_HOST locally}" cat /opt/reloj-ma/private-url.txt
```

## Access and HTTPS

`/opt/reloj-ma/.env` contains `SERVER_IP` and `ACCESS_PATH`. The latter contains a
256-bit secret generated using Python `secrets.token_hex(32)`. Both this file and
`private-url.txt` have mode 0600, inside a mode 0700 directory. All HTML, scripts,
fonts, source documents and model files require the complete secret path. Unknown
paths return 404; directory browsing is disabled. Anyone possessing the link can
use and share it. There are no individual accounts or per-person revocation.

Responses disable indexing, referrer transmission and caching. Access logging is
off; normal service logs retain startup, certificate and operational messages.
Do not enable HTTP access logs, publish browser traces, or paste the URL into
public monitoring services. Browser history and bookmarks can still retain it.
Simulation state is stored in each user's browser, not on the server.

Caddy obtains and automatically renews a publicly trusted Let's Encrypt IP
certificate with the `shortlived` ACME profile. Keep ports 80/443 reachable for
certificate validation, and preserve the `reloj-ma_caddy_data` and
`reloj-ma_caddy_config` Docker volumes across updates. `default_sni` allows IP
clients that omit TLS SNI. See the official [Caddy TLS configuration](https://caddyserver.com/docs/caddyfile/directives/tls)
and [Let's Encrypt IP certificate announcement](https://letsencrypt.org/2026/03/11/shorter-certs-certbot).

## Operate

```sh
ssh "${DEPLOY_HOST:?Set DEPLOY_HOST locally}" systemctl status reloj-ma.service
ssh "${DEPLOY_HOST:?Set DEPLOY_HOST locally}" systemctl restart reloj-ma.service
ssh "${DEPLOY_HOST:?Set DEPLOY_HOST locally}" 'cd /opt/reloj-ma && docker compose logs --tail=50 web'
```

`systemctl stop reloj-ma` stops the application. To prevent startup at boot as
well, use `systemctl disable --now reloj-ma`.

## Update or roll back

Run from the repository root. Each build gets its own release directory; the
relative `site/current` symlink switches atomically inside Caddy's existing mount.
Previous releases remain available for rollback.

```sh
npm ci --prefix simulator
npm run build --prefix simulator
release_id="$(date -u +%Y%m%dT%H%M%SZ)-$(git rev-parse --short HEAD)"
ssh "${DEPLOY_HOST:?Set DEPLOY_HOST locally}" "mkdir -p /opt/reloj-ma/site/releases/$release_id"
rsync -az simulator/dist/ "${DEPLOY_HOST:?Set DEPLOY_HOST locally}:/opt/reloj-ma/site/releases/$release_id/"
ssh "${DEPLOY_HOST:?Set DEPLOY_HOST locally}" "cd /opt/reloj-ma/site && ln -s releases/$release_id current.next && mv -Tf current.next current"
```

For rollback, point `site/current` at a retained directory under `site/releases`
using the same `current.next` and `mv -Tf` sequence. No container restart is needed
for an application update.

For server configuration changes, copy `Caddyfile`, `compose.yaml` and
`reloj-ma.service` from this directory to `/opt/reloj-ma`. Validate with
`docker compose run --rm --no-deps web caddy validate --config /etc/caddy/Caddyfile --adapter caddyfile`
from that directory. Install the unit into `/etc/systemd/system/reloj-ma.service`,
run `systemctl daemon-reload`, then `systemctl restart reloj-ma`.

Run all browser scenarios against the live production build without printing the
private URL in the command:

```sh
SIMULATOR_URL="$(ssh "${DEPLOY_HOST:?Set DEPLOY_HOST locally}" cat /opt/reloj-ma/private-url.txt)" npm run test:e2e --prefix simulator
```

## Revoke a shared link

Run the following on the server as root. It replaces the secret and recreates the
container with the new environment. Previously downloaded content cannot be
revoked, but the old link stops serving content.

```sh
cd /opt/reloj-ma
python3 - <<'PY'
from pathlib import Path
import os, secrets
os.umask(0o077)
settings = dict(line.split('=', 1) for line in Path('.env').read_text().splitlines() if '=' in line)
ip = settings['SERVER_IP']
access = '/reloj-ma-32-2/' + secrets.token_hex(32)
Path('.env').write_text(f'SERVER_IP={ip}\nACCESS_PATH={access}\n')
Path('private-url.txt').write_text(f'https://{ip}{access}/\n')
PY
docker compose up -d --force-recreate
cat private-url.txt
```

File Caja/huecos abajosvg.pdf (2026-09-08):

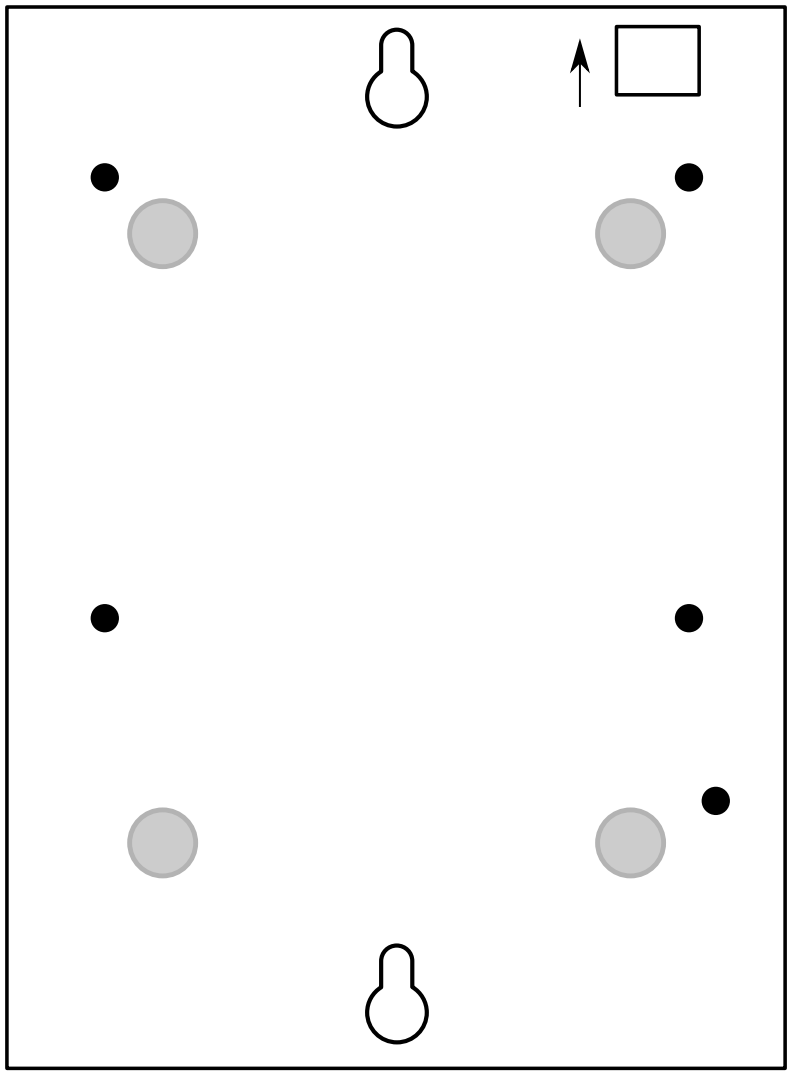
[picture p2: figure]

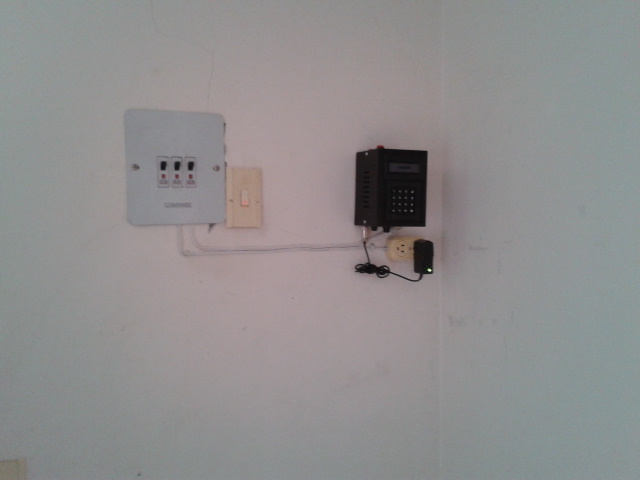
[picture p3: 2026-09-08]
Folleto/Fotos/2012-06-14 15.21.06.jpg

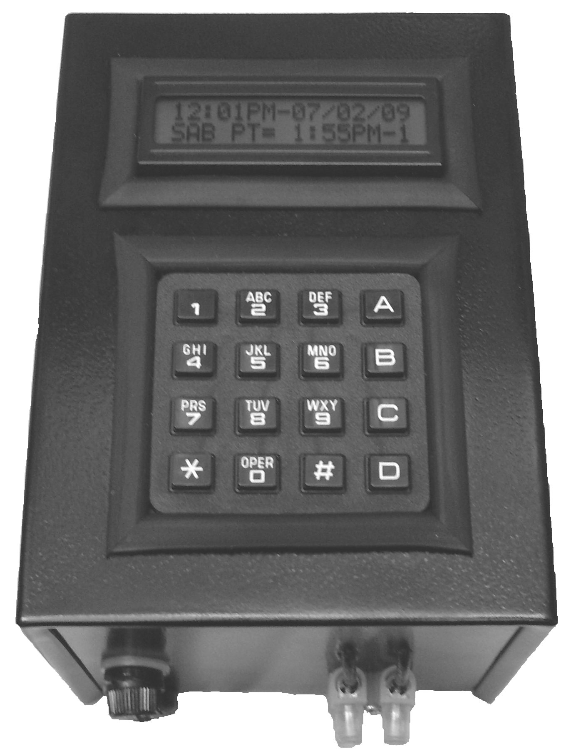
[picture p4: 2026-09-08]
Pagina/fotofrente.png

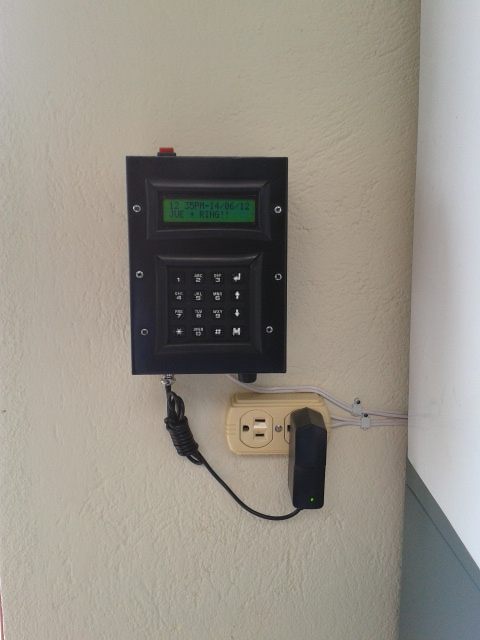
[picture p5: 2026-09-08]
Folleto/Fotos/2012-06-14 12.33.24.jpg

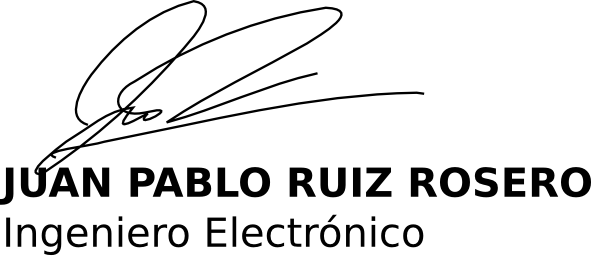
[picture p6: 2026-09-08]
Folleto/partes/firma2.png

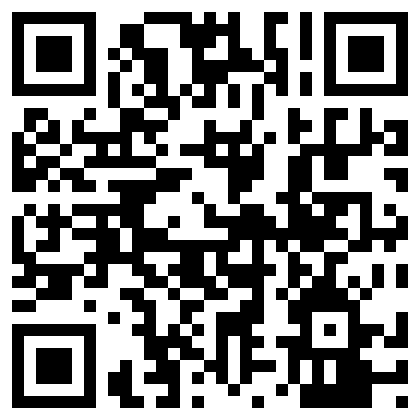
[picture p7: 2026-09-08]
Pagina/direccion.png

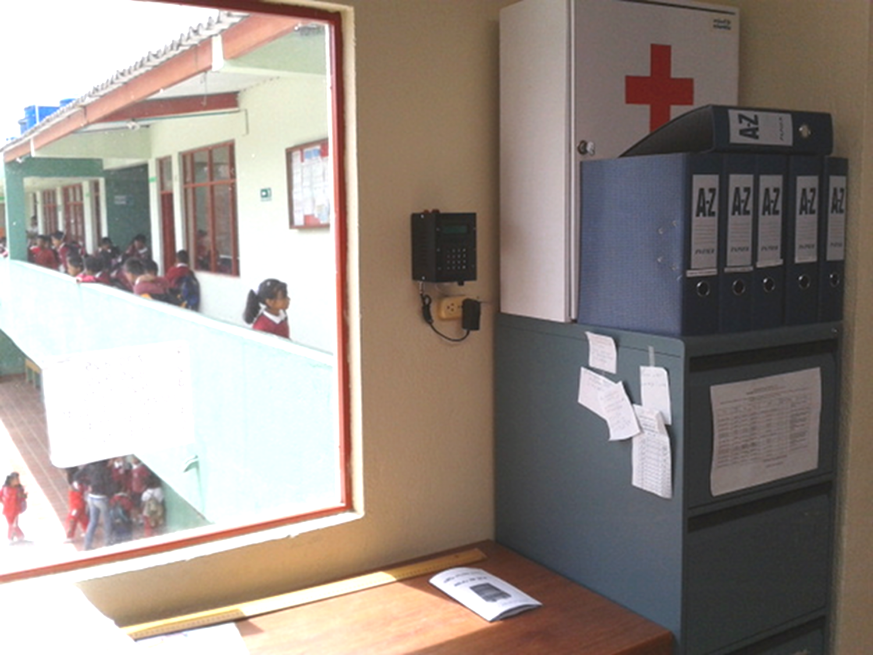
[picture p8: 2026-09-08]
Folleto/Fotos/lejos.png

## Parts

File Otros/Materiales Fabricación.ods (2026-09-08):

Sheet: Materiales
No |  | Precio | Lugar | Pedido 2012
1 | PIC16F877A | $8.000 | TNC | 8
2 | Patalla LCD dos lineas 16 caracteres | $9.000 | TNC | 6
3 | Caja metálica C57 | $10.000 | Sanyo
4 | Teclado hexadecimal | $10.000 | TNC
5 | DS1307 | $3.500 | TNC | 5
6 | Rele 12v 40A | $3.900 | Sanyo
7 | Base Rele 5 Patas | $2.000 | Electricos
8 | CRISTIAL 32.768KHz | $500 | TNC
9 | CRISTIAL 4MHz | $1.000 | TNC | 5
10 | PILA CR2032 | $1.000 | Sanyo | 10
11 | Fuente de 12v | $7.000 | Sanyo
12 | Conector fuente | $2.000 | Sanyo
13 | Resistencias 1/4w * 5 1K | $100 | Sanyo | 200
14 | Porta pila 2032 | $700 | Sanyo
15 | Condesador 1000uF x 16 | $250 | Sanyo | 24
16 | Capacitor 22pF | $100 | Sanyo | 50
17 | Capacitor 100nF | $100 | Sanyo | 100
 | Diodo zener de 5.6 |  |  | 20
18 | Diodo zener de 13,2 | $200 | Sanyo | 20
19 | Transistor 2N2222 | $200 | Sanyo | 40
20 | LM7805 | $700 | Sanyo | 10
22 | Circuito impreso | $7.000 | PCB Microcircuitos
23 | Base 40 pines | $300 | Sanyo | 10
24 | Cinta con conector x12 | $1.000 | TNC | 2
25 | Cinta con conector x 2 | $500 | Sanyo | 30
26 | Cinta con conector x8 | $2.000 | TNC | 2
27 | Cable interno | $2.000 | Sanyo
28 | Tornillos | $2.000 | Todo torinillo
29 | Pegante | $1.000 | Cordilleras
31 | Porta fusible caja grande | $600 | Sanyo
 | Fusible largo 15A |  |  | 40
33 | Disipador pequeño | $500 | Sanyo
34 | Reostato 5k | $250 | Sanyo | 5
35 | Switche Ref 67130 | $1.000 | Sanyo
36 | Pintura | $5.000 | Ferreteria
37 | Manual | $2.000 | Casa
38 | Regleta | $500 | Ferreteria
39 | Gastos varios
40
41 | Mano de obra (hora) * 8 | $80.000
 | TOTAL | $165.900
 | 265800
 | -15
 | 280800
 | Cuenta tnc Bancolombia corriente
 | 141 320 57 422
 | Nit: 900136510-4

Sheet: Cotizaciones
Articulo | Precio | Empresa | Fecha
PIC16F627 | $8,500 | Sanyo | 12/05/1008
MOC3041 | $2,000 | KUTIN | 09/12/2008
Contactor 110V 10A para base | $8,500 | Sanyo | 12/05/2008
Contactor Wusley LC1D12 12 A | $14,000 | Electricos Boyaca | 12/05/2008
Contactor Wusley LC1D18 18 A | $20,000 | Electricos Boyaca | 12/05/2008
Contactor Wusley LC1D2 40A 110v | $22,000 | Casa Electrica | 12/05/2008
PIC16F84A-04 | $10,800 | Sanyo | 12/05/2008
Triac BT134 4A | $1,500 | KUTIN | 12/05/2008
MOC3011 | $1,500 | KUTIN | 12/09/2008
MOC3020 | $1,400 | KUTIN | 12/09/2008
MOC3021 | $1,500 | KUTIN | 12/09/2008
CRISTIAL 32.768KHz x 24 y envio | $23,710 | SUCONEL | 12/10/2008
Clavija lateral | $950 | Radio AMFM | 01/08/2009
Metro cable duplex 2x16 | $550 | Radio AMFM | 01/08/2009
Pila CR2016 por 10 c/u | $1,500 | Centro comercial la 16 | 01/08/2009
Pila CR2032 por 10 c/u | $2,000 | Centro comercial la 16 | 01/08/2009
Puente de diodos 1A | $600 | Radio AMFM | 01/08/2009
Timbre chicharra Vera 18W | $9,500 | Radio AMFM | 01/08/2009
Transformador Tech 2.7W 9V dual 300mA | $6,800 | Radio AMFM | 01/08/2009
1 Regleta | $2,000 | Radio AMFM | 01/13/2009
Base 6p para MOC | $100 | KUTIN | 01/13/2009
Broca angosta | $250 | KUTIN | 01/13/2009
Broca con base gruesa | $750 | KUTIN | 01/13/2009
Cloruro Ferrico para un litro | $400 | KUTIN | 01/13/2009
Conector Mod 2 pines | $200 | KUTIN | 01/13/2009
Contactor SASSIN LC1 D1210 | $15,000 | Electricos Boyaca | 01/13/2009
Fusibles 10 y 20 A | $100 | KUTIN | 01/13/2009
Metro alabre 10 cobre | $1,700 | Radio AMFM | 01/13/2009
Porta fusible grande para baquelita | $600 | KUTIN | 01/13/2009
Relevo 6v 10A | $1,500 | KUTIN | 01/13/2009
Resistencias | $25 | KUTIN | 01/13/2009
Triac BTA08-600 8A | $2,500 | KUTIN | 01/13/2009
Triac Q6015L5 15A | $4,500 | KUTIN | 01/13/2009
Base 40 pines | $300 | Sanyo | 01/19/2009
Caja metalica C57 | $9,200 | Sanyo | 01/19/2009
Cloruro ferrico para un litro | $600 | Sanyo | 01/19/2009
Condensadores 1000 x 16 | $250 | Sanyo | 01/19/2009
Conector interno mole | $30 | Sanyo | 01/19/2009
Conector mole x8 macho y hembra | $600 | Sanyo | 01/19/2009
Cristal 4MHz | $1,200 | Sanyo | 01/19/2009
Didodos 1A | $50 | Sanyo | 01/19/2009
Disipador mediano 25451 | $1,400 | Sanyo | 01/19/2009
DS1307 | $7,300 | Sanyo | 01/19/2009
LM7805 | $700 | Sanyo | 01/19/2009
Patalla LCD dos lineas 16 caracteres | $14,000 | Sanyo | 01/19/2009
Pertinax 15x10 | $950 | Sanyo | 01/19/2009
PIC16F877A | $12,000 | Sanyo | 01/19/2009
Pila CR 2032 | $1,300 | Sanyo | 01/19/2009
Porta fusible caja pequeño | $600 | Sanyo | 01/19/2009
Porta pila 2032 | $700 | Sanyo | 01/19/2009
Puente de didos 2A | $600 | Sanyo | 01/19/2009
Resistencias | $20 | Sanyo | 01/19/2009
Resistencias 1 Ohm a 5W | $250 | Sanyo | 01/19/2009
Teclado hexadecimal | $7,900 | Sanyo | 01/19/2009
Transformador 9v 350mA | $3,500 | Sanyo | 01/19/2009
Transistor 2N2222 | $200 | Sanyo | 01/19/2009
Triac Q6015L5 15A | $3,900 | Sanyo | 01/19/2009

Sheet: Ped Jul 20-12
No |  | Precio | Lugar
1 | PIC16F877A | $8,000 | TNC
2 | Patalla LCD dos lineas 16 caracteres | $9,000 | TNC | 2 | 20000
3 | Caja metálica C57 | $10,000 | Sanyo
4 | Teclado hexadecimal | $10,000 | TNC | 10 | 120000
5 | DS1307 | $3,500 | TNC | 10 | 35000
6 | Rele 12v 40A | $3,900 | Sanyo
7 | Base Rele 5 Patas | $2,000 | Electricos
8 | CRISTIAL 32.768KHz | $500 | TNC | 20 | 14000
9 | CRISTIAL 4MHz | $600 | TNC | 10 | 6000
10 | PILA CR2032 | $1,000 | Sanyo
11 | Fuente de 12v | $7,000 | Sanyo
12 | Conector fuente | $2,000 | Sanyo
13 | Resistencias 1/4w * 5 | $100 | Sanyo
14 | Porta pila 2032 | $700 | Sanyo
15 | Condesador 1000uF x 16 | $250 | Sanyo
16 | Capacitor 22pF | $100 | Sanyo
17 | Capacitor 100nF | $100 | Sanyo
18 | Diodos zener | $200 | Sanyo
19 | Transistor 2N2222 | $200 | Sanyo
20 | LM7805 | $700 | Sanyo
21 | Pulsador NA Ref 6746B | $500 | Sanyo
22 | Circuito impreso | $7,000 | PCB Microcircuitos
23 | Base 40 pines | $300 | Sanyo
24 | Cinta con conector x12 | $2,500 | TNC | 10 | 25000
25 | Conector mole x2 macho y hembra | $500 | Sanyo
26 | Cinta con conector x8 | $2,200 | TNC | 10 | 22000
27 | Cable interno | $2,000 | Sanyo
28 | Tornillos | $2,000 | Todo torinillo
29 | Pegante | $1,000 | Cordilleras
31 | Porta fusible caja grande | $600 | Sanyo
33 | Disipador pequeño | $500 | Sanyo
34 | Reostato 5k | $250 | Sanyo
35 | Switche Ref 67130 | $1,000 | Sanyo
36 | Pintura | $5,000 | Ferreteria
37 | Manual | $2,000 | Casa
38 | Regleta | $500 | Ferreteria
39 | Gastos varios
40
41 | Mano de obra (hora) * 8 | $80,000 |  |  | 242000
 | TOTAL | $167,700

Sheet: Hoja3
PIC16F877A | $12,000 | 9000 | $120,000 | 90000
Patalla LCD dos lineas 16 caracteres | $16,000 | 11000 | $160,000 | 110000
CRISTIAL 32.768KHz | $1,000 | 800 | $10,000 | 8000
CRISTIAL 4MHz | $1,200 | 600 | $12,000 | 6000
DS1307 | $7,300 | 4500 | $73,000 | 45000
 | $37,500 | 25900 | $375,000 | 259000
 | $11,600 |  | $116,000

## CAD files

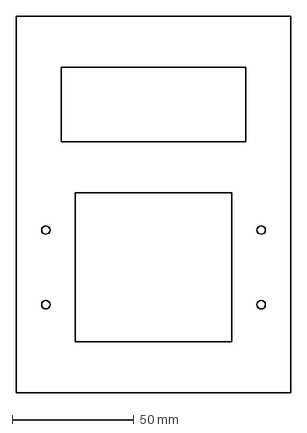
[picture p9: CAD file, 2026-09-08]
Caja/Antiguas medidas/frente.dxf
113.0 x 155.0 mm

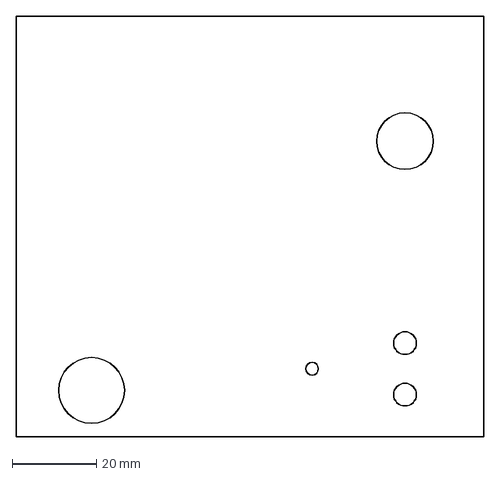
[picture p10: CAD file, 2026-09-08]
Caja/conectores.dxf
110.6 x 99.6 mm

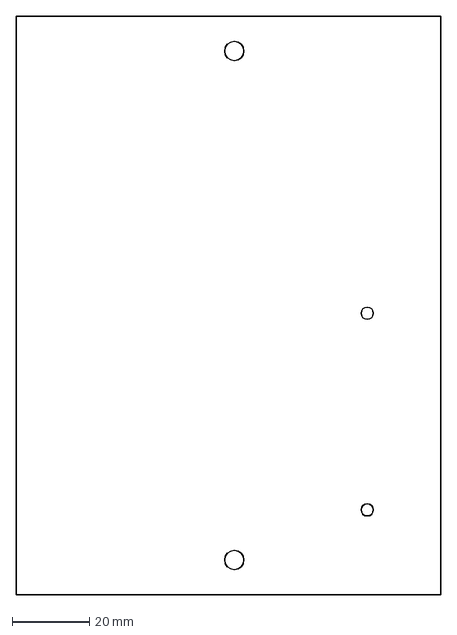
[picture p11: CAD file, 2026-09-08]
Caja/Antiguas medidas/fondo.dxf
110.0 x 150.0 mm

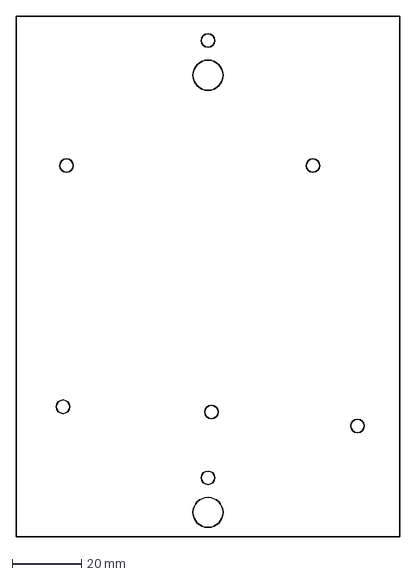
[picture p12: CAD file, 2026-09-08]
Caja/inferior.dxf
110.7 x 150.2 mm

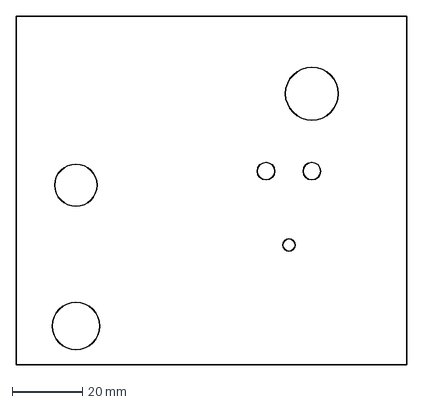
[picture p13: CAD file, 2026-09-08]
Caja/Antiguas medidas/inferior.dxf
111.0 x 99.0 mm

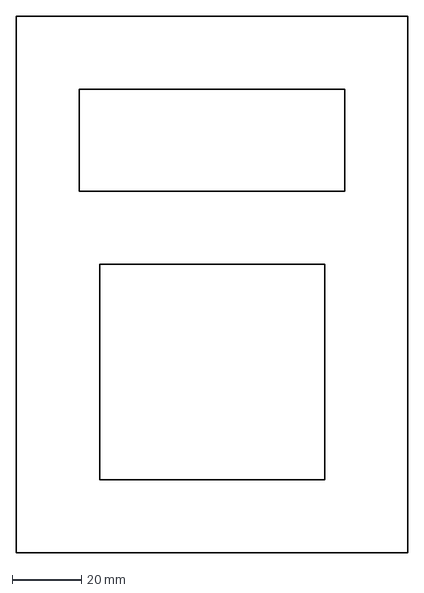
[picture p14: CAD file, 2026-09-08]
Caja/frente.dxf
113.1 x 154.8 mm

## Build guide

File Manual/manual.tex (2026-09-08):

\documentclass[10pt,notitlepage,openany]{scrbook}
\usepackage{anysize}
\paperwidth = 13.95cm
\paperheight = 21.6cm
\marginsize{1.5cm}{1.5cm}{1.5cm}{1.5cm} %\marginsize{izq}{der}{sup}{inf }

\usepackage{bera}		% Define el tipo de letra
\usepackage{arev}
\usepackage{hyperref}

%\oddsidemargin = 4cm
%\evensidemargin = 2cm
%\usepackage[left=6.8cm,top=6cm,right=0cm]{geometry} 
%left 0=2.8,
%\documentclass[bsc,draft,singlespacing]{csthesis}
%\documentclass[bsc,doublespacing]{csthesis}
      
\usepackage[spanish]{babel}     % Idioma de Captulos y dems
\usepackage[T1]{fontenc} 
\usepackage[utf8x]{inputenc}

\usepackage{titlesec}
\titleformat{\chapter}[hang]{\LARGE\bfseries}{\thechapter}{1em}{\bfseries}
\titlespacing{\chapter}{0pt}{-1cm}{1cm}

\usepackage{hyperref}

\usepackage{mathcomp}
\usepackage{latexsym}
\usepackage{pifont}
\usepackage{amsfonts}
\usepackage{amssymb}
\usepackage{wasysym}
\usepackage{colortbl}
\usepackage{multicol} 
\usepackage{booktabs}

\usepackage{graphicx}

\setlength{\parindent}{0cm}
\setlength{\parskip}{0.3cm}

\title{Manual Reloj MA 32-2}
\author{Galeras Digital}

\begin{document}
\pagestyle{empty}

\begin{figure}[ht]
	\begin{center}
		 
	\end{center}
\end{figure}

\tableofcontents 
\pagestyle{plain}
\chapter{Descripción General}

El Reloj MA 32-2 es un dispositivo electrónico digital que cuenta con un reloj calendario y la posibilidad de programar 30 distintas alarmas con diversas opciones de timbrado en cuatro diferentes tipos de horarios. Maneja un contacto de potencia capaz de soportar hasta 15A a 120VAC (1800W), una memoria interna tipo EEPROM donde se almacena la configuración de las alarmas sin perder los datos por hasta 40 años, una pila tipo CR2032 para no perder la fecha y hora en caso de fallas del fluido eléctrico y un menú en pantalla LCD que facilita su manejo.

\textit{Ventajas:}

La precisión en el timbre para el cambio de hora, es de gran importancia para toda la comunidad educativa, pero especialmente para el docente quien podrá programar sus actividades de clase con la plena seguridad de que el timbre de cambio de hora sonará con una precisión de segundos. 

La labor diaria y constante del toque del timbre se olvidará por completo, ya que el Reloj MA 32-2 se programa por una sola vez y no requiere de ninguna otra operación.

\section{Características}

\textit{Cuatro Horarios:} El Reloj MA 32-2 permite programar cuatro horarios distintos, cada uno hasta con 30 timbrasos, los cuales se pueden asignar independientemente a los diferentes días de la semana.

\textit{Fácil Manejo:} Su programación es muy sencilla y se realiza por una sola vez, esta no se borrará aunque se suspenda el fluido eléctrico.

\textit{Pila de respaldo:} El Reloj MA 32-2 cuenta con una pila de respaldo la cual permite al sistema mantener la fecha y la hora en caso de cortes en el fluido eléctricºo. La pila usada, CR2032 tiene una duración aproximada de 10 años y se consigue fácilmente en cualquier relojería o tienda electronica.

\textit{Pantalla LCD:} Su pantalla LCD retro iluminada, facilita la programación y muestra constantemente la hora exacta y la hora del próximo timbre. 

\textit{Teclado Numérico:} Su teclado numérico y de funciones permite una fácil programación de los timbrados y el cambio de horario.

\textit{Adaptabilidad:} El Reloj MA 32-2 se instala y adapta fácilmente a cualquier sistema de timbre, chicharra o sistema de alarma.

\textit{Seguridad:} El Reloj MA 32-2 posee un sistema de seguridad que solicita una clave o contraseña, para evitar que personas no autorizadas accedan o modifiquen la programación.

\textit{Calidad:} El Reloj MA 32-2 está elaborado con materiales de altísima calidad lo que garantiza un funcionamiento preciso e ininterrumpido durante muchos años.

\newpage

\section{Vista frontal}

En la parte frontal se encuentra una pantalla LCD y un teclado de números y funciones con los cuales se opera el Reloj MA 32-2.

\begin{figure}[ht] 
        \caption[Vista frontal]{Vista frontal}
        \begin{center}
                 
        \end{center}
	\label{frente1}
\end{figure}

\newpage

\section{Vista inferior}

En la parte inferior se encuentra la entrada de corriente de 12VDC, un fusible de 15A que protege el contacto interno y el conector de potencia donde se conecta el circuito de los timbres.

\begin{figure}[ht]
        \caption[Vista inferior]{Vista inferior}
        \begin{center}
                 
        \end{center}
	\label{inferior1}
\end{figure}

\newpage
\section{Vista superior}

En la parte superior se encuentra un interruptor de timbrado automático que tiene como función la activación o desactivación del timbrado automático. Cuando el interruptor se encuentra del lado del punto blanco, el sistema de timbrado automático esta activado. Cuando el interruptor esta en el sentido contrario, el sistema de timbrado automático estará desactivado y el Reloj MA 32-2 no timbrara. Esta última opción se la configura cuando hay días festivos o no hay clases.

\begin{figure}[ht] 
        \caption[Vista superior]{Vista superior}
        \begin{center}
                 
        \end{center}
	\label{superior1}
\end{figure}

\newpage
\section{Pantalla principal}

En la pantalla principal se muestra la hora actual (Hora : Minutos : Segundos) en formato AM/PM  seguida del día de la semana. En la segunda linea se encuentra la hora y el día próximo timbrado.

\textit{Nota: Si no existe ninguna alarma programada en los tipos de horario o ningún tipo de horario está asignado a algún día de la semana, el espacio donde se encuentra la hora y el día del próximo timbrado aparecerá en blanco.}

\begin{figure}[ht] 
        \caption[Pantalla principal]{Pantalla principal}
        \begin{center}
                 
        \end{center}
	\label{lcd1}
\end{figure}

\newpage
\section{Teclado de números y funciones}
Este teclado esta compuesto por una sección numérica y una sección de funciones. La tecla Enter () se usa para aceptar alguna opción, para acceder a un menú o validar un cambio. Las teclas  y  se usan como flechas arriba y abajo respectivamente para desplazarse entre el menú o diferentes opciones. Finalmente, la tecla  se usa para acceder o salir del Menú de configuración. 

Cada vez que se accede al menú la luz de fondo de la pantalla LCD se activa, al salir del menú, permanece activa esta luz por 10 segundos. La tecla asterisco (*) activa la luz por 10 segundos para poder visualizar los mensajes de la pantalla principal.

Por su parte la tecla \# activa el timbre cuando es presionada.

\begin{figure}[ht] % Se usa la [h] para que la imagen empiece forzada en el lugar donde inicia 

        \caption[Teclado de números y funciones]{Teclado de números y funciones}
        \begin{center}
                 % include ./img/imagen.[pdf|png|jgp] si es pdflatex o ./img/imagen.eps si es latex
        \end{center}
	\label{teclado1}
\end{figure}

\newpage
\section{Menú de configuración}

Con la tecla , se accede al menú de configuración en el cual el usuario puede desplazarse por las diferentes opciones con la ayuda de las teclas  y , para acceder a la opción deseada se presiona la tecla . El menú esta compuesto de las siguientes opciones que se describen en los capítulos posteriores.
\begin{itemize}
\item Fijar Reloj
\item Fijar Alarmas
\item Tipo de Horario
\item Contraseña
\item Dura. Timbres
\end{itemize}

\section{Interruptor de timbrado automático}

El interruptor de timbrado automático impide que el sistema cierre el contacto de potencia lo cual desactiva el timbrado automático programado, esta función ayuda a desactivar los timbres cuando el usuario lo desee por ejemplo en días feriados. El estado de encendido de este interruptor se distingue cuando este esta posicionado del lado del punto blanco.

\textit{Nota: Se recomienda colocar el Interruptor de timbrado automático en apagado al momento de conectar a la corriente eléctrica el Reloj MA 32-2 para evitar timbrados no deseados.}

\chapter{Fijar Reloj}

La opción Fijar Reloj permite ajustar la hora y la fecha actual, para ello se procede de la siguiente forma:
\begin{itemize}
\item Acceder al menú con el botón .
\item Desplazarse hasta la opción Fijar Reloj con los botones  y  y presionar el botón .
\item Establecer la hora, los minutos y los segundos con la ayuda de el teclado numérico.
\item Fijar AM o PM con la ayuda de las teclas  y  y luego presionar el botón .
\item Fijar el día de la semana con las teclas  y  y presionar finalmente el botón .
\end{itemize}

Una vez presionado el botón  después de fijar el día de la semana la hora queda establecida. El Reloj MA 32-2 cuenta con una pila interna CR2032 la cual es capaz de almacenar la hora en caso de fallas de energía por hasta 10 años. Si al momento de el restablecimiento de la energía la hora no es la correcta es necesario cambiar esta pila.

\chapter{Fijar Alarmas}

La opción Fijar Alarmas permite ajustar los 30 timbrasos dentro de cada uno de los 4 tipos de horario. Primero se escoge el tipo de horario a modificar con la ayuda de las teclas  y , se lo selecciona con el botón , luego la pantalla muestra la Figura \ref{lcdfalarmas} que indica el numero de la alarma, el tipo de horario a la que pertenece, la hora a la que está fijada ésta alarma, el tipo de timbrado y el estado de la alarma, apagada (OFF) o encendida (ON).

\begin{figure}[ht] 
        \caption[Pantalla fijar alarmas]{Pantalla fijar alarmas}
        \begin{center}
                 
        \end{center}
	\label{lcdfalarmas}
\end{figure}

Para desplazarse entre las alarmas se usan los botones  y , para fijar una alarma se pulsa el botón  estando en el numero de alarma que se desea modificar y se sigue este orden:
\begin{itemize}
\item Establecer la hora y los minutos de la alarma con la ayuda de el teclado numérico.
\item Fijar AM o PM con la ayuda de las teclas  y  y luego presionar el botón .
\item Fijar el tipo de timbrado con las teclas  y  y luego presionar el botón .
\item Fijar el estado de la alarma con las teclas  y  en encendida (ON) o apagada (OFF) y finalmente presionar el botón .
\end{itemize}

De esta misma forma se pueden fijar una o todas las alarmas. Cada vez que se configura una alarma estos datos quedan guardados en la memoria EEPROM del sistema lo que evita pérdida de los datos en caso de fallo de la energía.

\textit{Nota: No es necesario programar las alarmas en orden.	}

\section{Tipo de timbrado}

El Reloj MA 32-2 soporta 4 diferentes modos de timbrado, los cuales se describen a continuación:

\begin{itemize}
\item 1TC: 1 Timbre corto.
\item 1TL: 1 Timbre largo.
\item 2TC: 2 Timbres cortos.
\item 3TC: 3 Timbres cortos.
\end{itemize}

La duración de los intervalos de tiempo de los timbres se establecen con el menú Dura. Timbres, el cual se explica a continuación.

\newpage
\section{Dura. Timbres}

En el menú Dura. Timbres se establece la duración del timbre corto y del timbre largo, de la siguiente forma:

\begin{itemize}
\item Acceder al menú con el botón .
\item Desplazarse hasta la opción Dura. Timbres con los botones  y  y presionar el botón .
\item Establecer con los botones  y  la duración en segundos del timbre corto (TC) y presionar el botón .
\item Establecer con los botones  y  la duración en segundos del timbre largo (TL) y presionar finalmente el botón .
\end{itemize}

\section{Tipo de horario}

El menú tipo de horario permite asignar el tipo de horario a cada día de la semana, asignando uno de los cuatro tipos de horario o ningún horario con la opción OFF a cada día. Para configurar se procede de la siguiente forma:

\begin{itemize}
\item Acceder al menú con el botón .
\item Desplazarse hasta la opción Tipo de Horario con los botones  y  y presionar el botón .
\item Escoger el día que se desea modificar con los botones  y  y presionar el botón .
\item Seleccionar el tipo de horario con los botones  y  y presionar el botón  para guardar.
\item Presionar el botón  para salir.
\end{itemize}

\chapter{Contraseña}

El Reloj MA 32-2 tiene la opción de proteger su configuración mediante una contraseña de 4 números. Para configurar una contraseña proceda de la siguiente forma:

\begin{itemize}
\item Acceda al menú con el botón .
\item Desplazarse hasta la opción Contraseña con los botones  y  y presionar el botón .
\item Escoger si el sistema pide o no pide la contraseña con los botones  y  y presionar el botón .
\item Escribir los cuatro números de la contraseña.
\item Escribir nuevamente los cuatro números de la contraseña.
\end{itemize}

Una vez establecida la contraseña el Reloj MA 32-2 la pedirá cada vez que se acceda al menú, en donde existe un tiempo limite de 5 segundos para poderla escribir. Si se desea desactivar la contraseña se escoge NO a la pregunta pedir contraseña en este menú.

\textit{Nota: Si olvida la contraseña de seguridad debe desconectar el equipo y retirar la pila interna CR2032 durante al menos 10 segundos, esto borrara la contraseña y la hora actual.}

\chapter{Conexión de los timbres}

El Reloj MA 32-2 posee un conector de potencia el cual cierra el circuito cuando un timbrado es activado por una alarma o cuando se presiona la tecla \#. Este contacto soporta una corriente máxima de 15A en 100 a 240 VAC (1800W/3600W) y está esta protegido con un fusible de 15A.

Los timbres se deben conectar en paralelo con una rama al Neutro (N) de la instalación eléctrica y la otra rama al conector de potencia del Reloj MA 32-2, el otro contacto del conector de potencia debe ser conectado a la Linea (L) de la instalación eléctrica. Es muy importante que la instalación eléctrica soporte la corriente requerida por los timbres. El esquema de la Figura \ref{conpotencia} muestra de forma mas detallada la conexión.

\begin{figure}[ht] % Se usa la [h] para que la imagen empiece forzada en el lugar donde inicia \begin{figure}

        \caption[Esquema de conexión de timbres]{Esquema de conexión de timbres}
        \begin{center}
                 % include ./img/imagen.[pdf|png|jgp] si es pdflatex o ./img/imagen.eps si es latex
        \end{center}
	\label{conpotencia}
\end{figure}

Es muy importante calcular y medir la corriente que demanda la instalación de timbres que se tenga antes de conectar el Reloj MA 32-2, si la corriente demandada supera las características del Reloj MA 32-2 contacte a Galeras Digital para dar solución a sus nuevos requerimientos.

\textit{Nota: Galeras Digital no se hace responsable por daños causados debido a una instalación inadecuada o por fallas presentadas del fluido eléctrico.}

\chapter{Garantía}

Este producto esta garantizado por Galeras Digital al comprador original de estar libre de defectos en los materiales y fabricación bajo uso normal por un periodo de un año de la fecha de compra. Durante el periodo de garantía y con la factura de compra; el producto será reparado utilizando piezas de remplazo originales y si es el caso el producto será remplazado en su totalidad. Para obtener el servicio de garantía usted debe contactar a Galeras Digital y poseer una copia de su factura de compra que muestre la fecha de tal compra, usted no tendrá cargo por las piezas o la reparación.

El cliente NO tendrá reclamo alguno bajo esta garantía para gastos de reparaciones o ajustes si:

\begin{enumerate}
\item El problema es causado por un trato incorrecto, maltrato o descuido
\item Los sellos de garantía muestran señales de violación.
\item El problema es causado por un incendio u otro desastre natural.
\item El problema es causado por la reparación o ajuste inadecuado realizado por personas que no pertenecen a Galeras Digital.
\item El periodo de garantía ha expirado.
\end{enumerate}

\newpage

\section{Contactos}

Para contactar a Galeras Digital puede comunicarse al siguiente celular, correo electrónico o pagina web:
\
\\
\\
\begin{itemize}
\item\textbf{Ventas y soporte técnico:}
\subitem\textbf{- Juan Pablo Ruiz:} 301 323 4324
\subitem \hspace{0.5cm}(Cajicá - Colombia)
\item\textbf{Correo electrónico:} galerasdigital@gmail.com
\item\textbf{Pagina web:}\\ \url{http://www.galerasdigital.com}
\end{itemize}

\vspace{1cm}
\begin{tiny}\textit{M/V: 3.03-30x4/01/10/14}\end{tiny}\\
\begin{tiny}\textit{F/V: 30x4-06/12}\end{tiny}

\newpage
\pagestyle{empty}
\ \\
\vspace{3cm}
\begin{center}
 
 % tapaf.eps: 1111x654 pixel, 300dpi, 9.41x5.54 cm, bb=0 0 267 157
\end{center}

\end{document}

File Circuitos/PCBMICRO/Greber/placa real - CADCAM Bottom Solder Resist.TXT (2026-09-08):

G04 PROTEUS RS274X GERBER FILE*
%FSLAX24Y24*%
%MOIN*%
%ADD20C,0.0800*%
%ADD26R,0.1000X0.1000*%
%ADD27C,0.1300*%
%ADD28C,0.1100*%
%ADD19C,0.0900*%
%ADD29R,0.0900X0.0900*%
%ADD18C,0.1000*%
%ADD72C,0.4137*%
%ADD73C,0.2955*%
%ADD30O,0.3937X0.2755*%
%ADD31C,0.3543*%
%ADD25C,0.0080*%
G54D20*
X+32677Y-7480D03*
X+32677Y-3937D03*
X+36850Y-6050D03*
X+34200Y-6050D03*
G54D26*
X+3000Y-18750D03*
X+4000Y-18750D03*
G54D27*
X+1250Y-16050D03*
X+2750Y-16050D03*
X+4250Y-16050D03*
X+5750Y-16050D03*
X+1250Y-12500D03*
X+3250Y-12500D03*
G54D26*
X+2750Y-5250D03*
X+2750Y-4250D03*
X+2750Y-3250D03*
G54D28*
X+761Y-9253D03*
X+4761Y-9253D03*
G54D19*
X+36011Y-13488D03*
X+35011Y-13488D03*
X+18392Y-10445D03*
X+17392Y-10445D03*
G54D29*
X+12688Y-12371D03*
G54D19*
X+13688Y-12371D03*
X+14688Y-12371D03*
X+15688Y-12371D03*
X+16688Y-12371D03*
X+17688Y-12371D03*
X+18688Y-12371D03*
X+19688Y-12371D03*
X+20688Y-12371D03*
X+21688Y-12371D03*
X+22688Y-12371D03*
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

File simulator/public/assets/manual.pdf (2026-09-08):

# Reloj MA 32-2

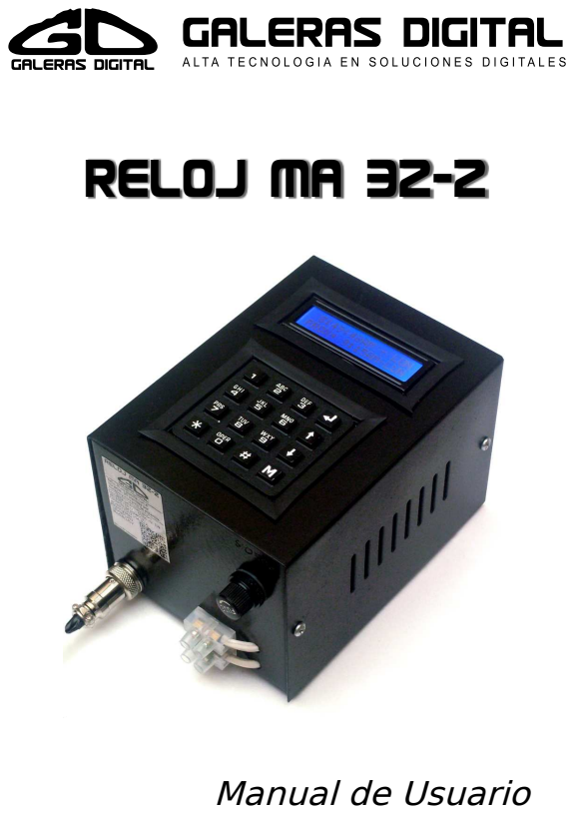
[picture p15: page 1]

Manual de Usuario

# Índice general

1. Descripción General | 3
2. Fijar Reloj | 11
3. Fijar Alarmas | 12
4. Contraseña | 15
5. Conexión de los timbres | 16
6. Garantía | 18

2

# 1 Descripción General

El Reloj MA 32-2 es un dispositivo electrónico digital que cuenta con un reloj calendario y la posibilidad de programar 30 distintas alarmas con diversas opciones de timbrado en cuatro diferentes tipos de horarios. Maneja un contacto de potencia capaz de soportar hasta 15A a 120VAC (1800W), una memoria interna tipo EEPROM donde se almacena la configuración de las alarmas sin perder los datos por hasta 40 años, una pila tipo CR2032 para no perder la fecha y hora en caso de fallas del fluido eléctrico y un menú en pantalla LCD que facilita su manejo.

Ventajas:

La precisión en el timbre para el cambio de hora, es de gran importancia para toda la comunidad educativa, pero especialmente para el docente quien podrá programar sus actividades de clase con la plena seguridad de que el timbre de cambio de hora sonará con una precisión de segundos.

La labor diaria y constante del toque del timbre se olvidará por completo, ya que el Reloj MA 32-2 se programa por una sola vez y no requiere de ninguna otra operación.

## 1.1. Características

Cuatro Horarios: El Reloj MA 32-2 permite programar cuatro horarios distintos, cada uno hasta con 30 timbrasos, los cuales se pueden asignar independientemente a los diferentes días de la semana.

Fácil Manejo: Su programación es muy sencilla y se realiza por

3

una sola vez, esta no se borrará aunque se suspenda el fluido eléctrico.

Pila de respaldo: El Reloj MA 32-2 cuenta con una pila de respaldo la cual permite al sistema mantener la fecha y la hora en caso de cortes en el fluido eléctricºo. La pila usada, CR2032 tiene una duración aproximada de 10 años y se consigue fácilmente en cualquier relojería o tienda electronica.

Pantalla LCD: Su pantalla LCD retro iluminada, facilita la programación y muestra constantemente la hora exacta y la hora del próximo timbre.

Teclado Numérico: Su teclado numérico y de funciones permite una fácil programación de los timbrados y el cambio de horario.

Adaptabilidad: El Reloj MA 32-2 se instala y adapta fácilmente a cualquier sistema de timbre, chicharra o sistema de alarma.

Seguridad: El Reloj MA 32-2 posee un sistema de seguridad que solicita una clave o contraseña, para evitar que personas no autorizadas accedan o modifiquen la programación.

Calidad: El Reloj MA 32-2 está elaborado con materiales de altísima calidad lo que garantiza un funcionamiento preciso e ininterrumpido durante muchos años.

4

## 1.2. Vista frontal

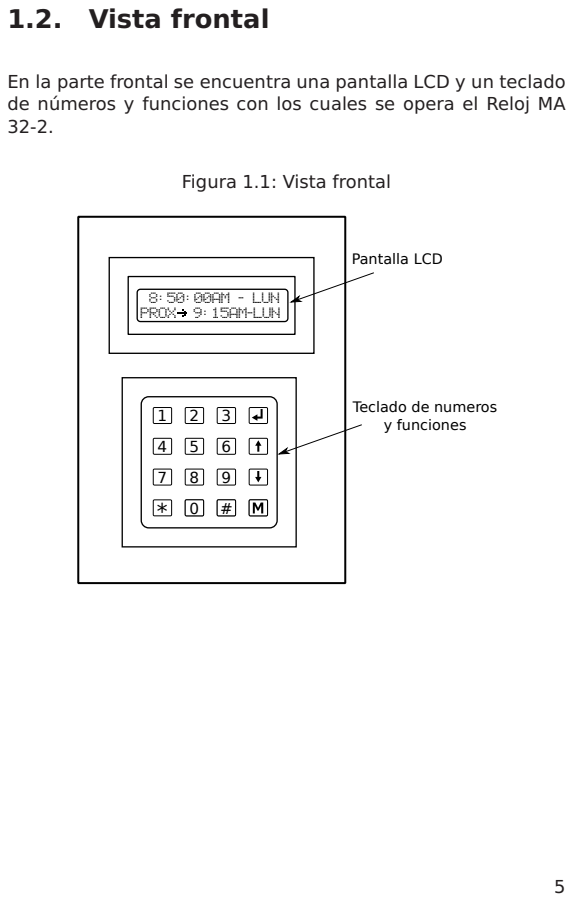
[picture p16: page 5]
Pantalla LCD; 8:50:00AM - LUN; PROX; 9:15AM-LUN

En la parte frontal se encuentra una pantalla LCD y un teclado
de números y funciones con los cuales se opera el Reloj MA

Figura 1.1: Vista frontal

Teclado de numeros
y funciones

## 1.3. Vista inferior

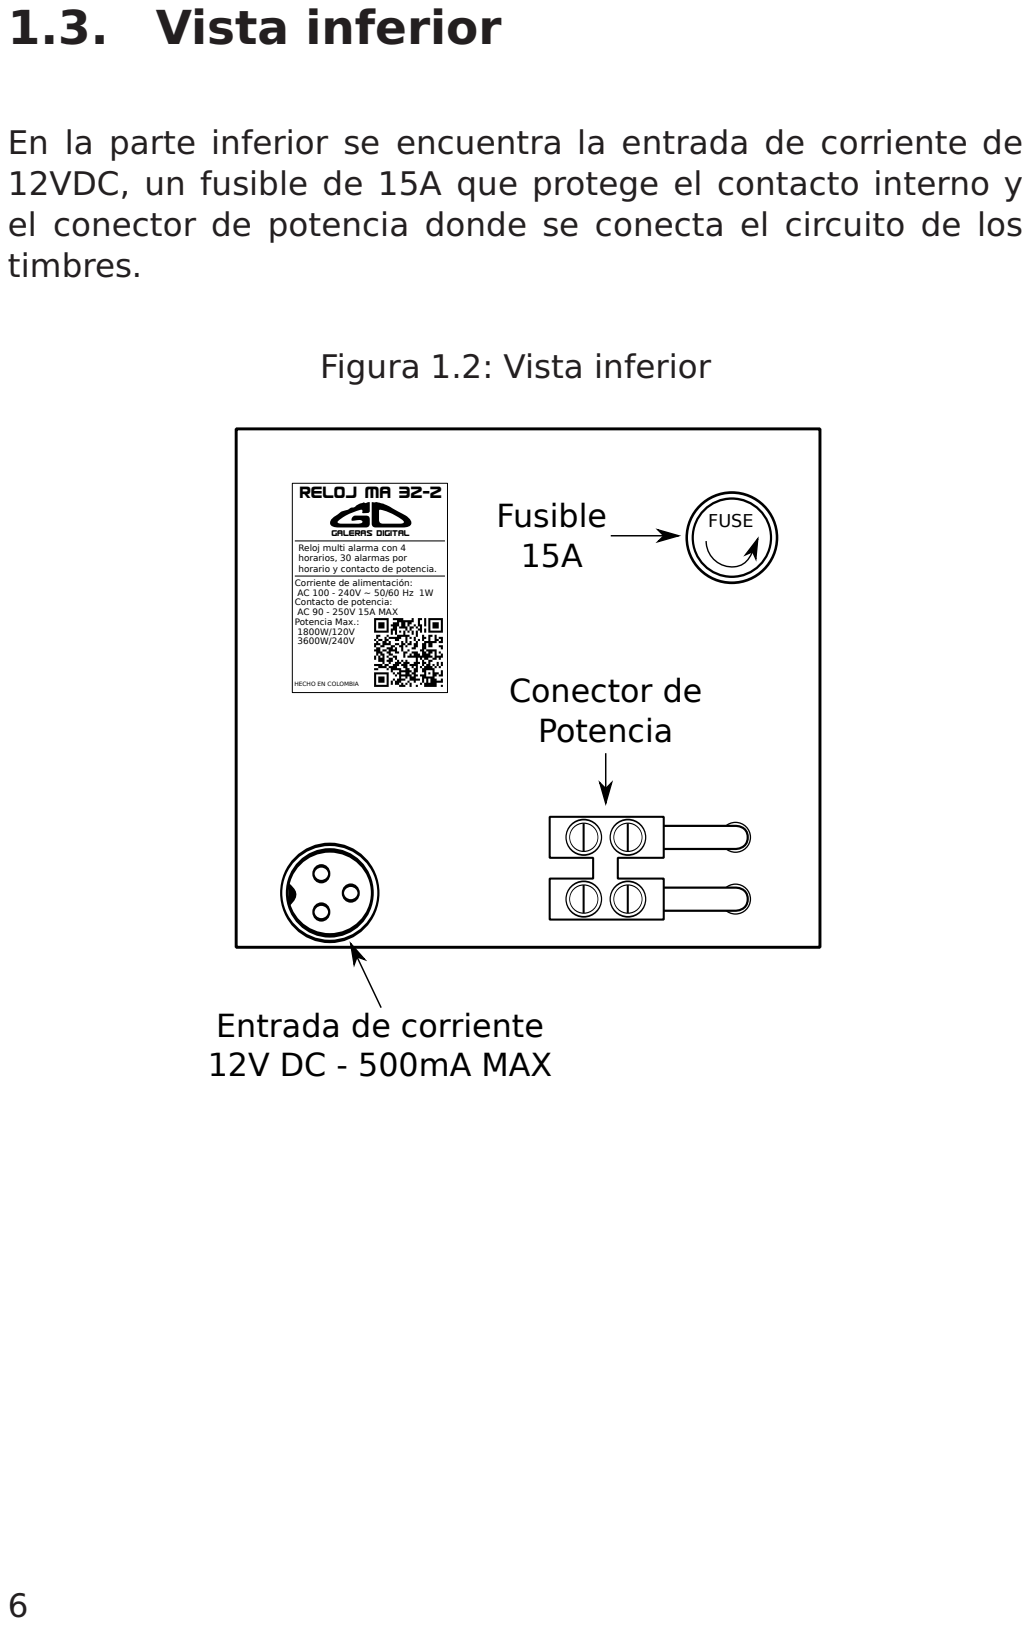
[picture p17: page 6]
Conector de Potencia; Fusible; FUSE; reloj mA 32-2; GALERAS DIGITAL

En la parte inferior se encuentra la entrada de corriente de
12VDC, un fusible de 15A que protege el contacto interno y
el conector de potencia donde se conecta el circuito de los
timbres.

Figura 1.2: Vista inferior

Reloj multi alarma con 4
horarios, 30 alarmas por
horario y contacto de potencia.
Corriente de alimentación:
Contacto de potencia:
AC 90 - 250V 15A MAX
Potencia Max.:

HECHO EN COLOMBIA

Entrada de corriente
12V DC - 500mA MAX

## 1.4. Vista superior

En la parte superior se encuentra un interruptor de timbrado automático que tiene como función la activación o desactivación del timbrado automático. Cuando el interruptor se encuentra del lado del punto blanco, el sistema de timbrado automático esta activado. Cuando el interruptor esta en el sentido contrario, el sistema de timbrado automático estará desactivado y el Reloj MA 32-2 no timbrara. Esta última opción se la configura cuando hay días festivos o no hay clases.

Figura 1.3: Vista superior

7

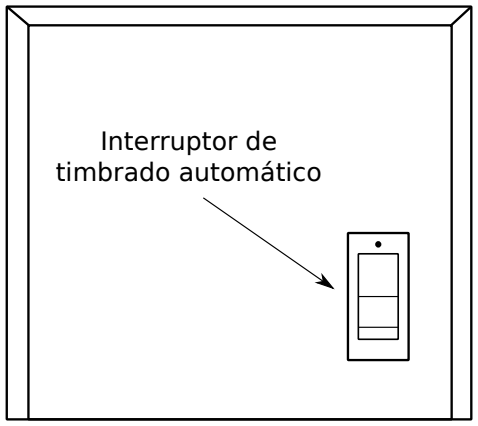
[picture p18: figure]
Interruptor de timbrado automático

## 1.5. Pantalla principal

En la pantalla principal se muestra la hora actual (Hora : Minutos : Segundos) en formato AM/PM seguida del día de la semana. En la segunda linea se encuentra la hora y el día próximo timbrado.

Nota: Si no existe ninguna alarma programada en los tipos de horario o ningún tipo de horario está asignado a algún día de la semana, el espacio donde se encuentra la hora y el día del próximo timbrado aparecerá en blanco.

Figura 1.4: Pantalla principal

Hora actual | Día actual

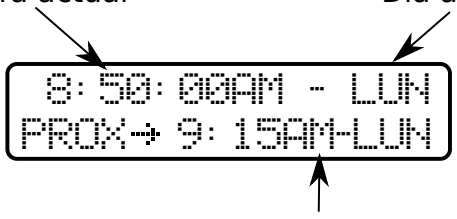
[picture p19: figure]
8:50:00AM - LUN; PROX; 9:15AM-LUN

### Hora y día del próximo timbre

8

## 1.6. Teclado de números y funciones

Este teclado esta compuesto por una sección numérica y una sección de funciones. La tecla Enter ( ) se usa para aceptar alguna opción, para acceder a un menú o validar un cambio. Las teclas y se usan como flechas arriba y abajo respectivamente para desplazarse entre el menú o diferentes opciones. Finalmente, la tecla se usa para acceder o salir del Menú de configuración.

Cada vez que se accede al menú la luz de fondo de la pantalla LCD se activa, al salir del menú, permanece activa esta luz por

### 10 segundos. La tecla asterisco (*) activa la luz por 10 segun-

dos para poder visualizar los mensajes de la pantalla principal.

Por su parte la tecla # activa el timbre cuando es presionada.

Figura 1.5: Teclado de números y funciones

* 0 | #
7 | 8 | 9
4 | 5 | 6
1 | 2 | 3 | Tecla Enter
| | | Tecla Arriba
| | | Tecla Abajo
| | | Tecla Menú
Tecla ( ) luz de fondo | Tecla (#) para timbrado manual

9

## 1.7. Menú de configuración

Con la tecla , se accede al menú de configuración en el cual el usuario puede desplazarse por las diferentes opciones con la ayuda de las teclas y , para acceder a la opción deseada se presiona la tecla . El menú esta compuesto de las siguientes opciones que se describen en los capítulos posteriores.

Fijar Reloj

Fijar Alarmas

Tipo de Horario

Contraseña

Dura. Timbres

## 1.8. Interruptor de timbrado automático

El interruptor de timbrado automático impide que el sistema cierre el contacto de potencia lo cual desactiva el timbrado automático programado, esta función ayuda a desactivar los timbres cuando el usuario lo desee por ejemplo en días feriados. El estado de encendido de este interruptor se distingue cuando este esta posicionado del lado del punto blanco.

Nota: Se recomienda colocar el Interruptor de timbrado automático en apagado al momento de conectar a la corriente eléctrica el Reloj MA 32-2 para evitar timbrados no deseados.

10

# 2 Fijar Reloj

La opción Fijar Reloj permite ajustar la hora y la fecha actual, para ello se procede de la siguiente forma:

Acceder al menú con el botón .

Desplazarse hasta la opción Fijar Reloj con los botones y y presionar el botón .

Establecer la hora, los minutos y los segundos con la ayuda de el teclado numérico.

Fijar AM o PM con la ayuda de las teclas | y | y luego
presionar el botón .

Fijar el día de la semana con las teclas y y presionar finalmente el botón .

Una vez presionado el botón después de fijar el día de la semana la hora queda establecida. El Reloj MA 32-2 cuenta con una pila interna CR2032 la cual es capaz de almacenar la hora en caso de fallas de energía por hasta 10 años. Si al momento de el restablecimiento de la energía la hora no es la correcta es necesario cambiar esta pila.

11

# 3 Fijar Alarmas

La opción Fijar Alarmas permite ajustar los 30 timbrasos dentro de cada uno de los 4 tipos de horario. Primero se escoge el tipo de horario a modificar con la ayuda de las teclas y , se lo selecciona con el botón , luego la pantalla muestra la Figura

### 3.1 que indica el numero de la alarma, el tipo de horario a

la que pertenece, la hora a la que está fijada ésta alarma, el tipo de timbrado y el estado de la alarma, apagada (OFF) o encendida (ON).

Figura 3.1: Pantalla fijar alarmas

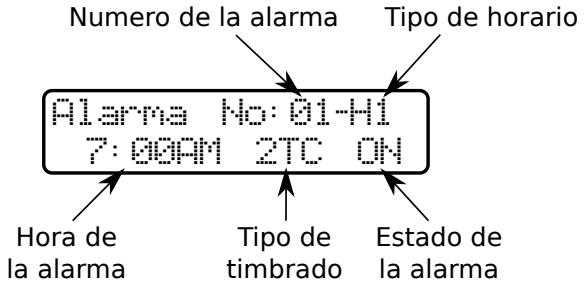
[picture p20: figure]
Alarma; Numero de la alarma; Tipo de horario; Hora de la alarma; Tipo de timbrado; Estado de la alarma

Para desplazarse entre las alarmas se usan los botones y , para fijar una alarma se pulsa el botón estando en el numero de alarma que se desea modificar y se sigue este orden:

Establecer la hora y los minutos de la alarma con la ayuda de el teclado numérico.

Fijar AM o PM con la ayuda de las teclas | y | y luego
presionar el botón .

Fijar el tipo de timbrado con las teclas y y luego pre-

12

sionar el botón .

Fijar el estado de la alarma con las teclas y en encendida (ON) o apagada (OFF) y finalmente presionar el botón .

De esta misma forma se pueden fijar una o todas las alarmas. Cada vez que se configura una alarma estos datos quedan guardados en la memoria EEPROM del sistema lo que evita pérdida de los datos en caso de fallo de la energía.

Nota: No es necesario programar las alarmas en orden.

## 3.1. Tipo de timbrado

El Reloj MA 32-2 soporta 4 diferentes modos de timbrado, los cuales se describen a continuación:

1TC: 1 Timbre corto.

1TL: 1 Timbre largo.

2TC: 2 Timbres cortos.

3TC: 3 Timbres cortos.

La duración de los intervalos de tiempo de los timbres se establecen con el menú Dura. Timbres, el cual se explica a continuación.

13

## 3.2. Dura. Timbres

En el menú Dura. Timbres se establece la duración del timbre corto y del timbre largo, de la siguiente forma:

Acceder al menú con el botón .

Desplazarse hasta la opción Dura. Timbres con los botones y y presionar el botón .

Establecer con los botones y la duración en segundos del timbre corto (TC) y presionar el botón .

Establecer con los botones y la duración en segundos del timbre largo (TL) y presionar finalmente el botón .

## 3.3. Tipo de horario

El menú tipo de horario permite asignar el tipo de horario a cada día de la semana, asignando uno de los cuatro tipos de horario o ningún horario con la opción OFF a cada día. Para configurar se procede de la siguiente forma:

Acceder al menú con el botón .

Desplazarse hasta la opción Tipo de Horario con los botones y y presionar el botón .

Escoger el día que se desea modificar con los botones y y presionar el botón .

Seleccionar el tipo de horario con los botones y y pre-
sionar el botón | para guardar.
Presionar el botón | para salir.

14

# 4 Contraseña

El Reloj MA 32-2 tiene la opción de proteger su configuración mediante una contraseña de 4 números. Para configurar una contraseña proceda de la siguiente forma:

Acceda al menú con el botón .

Desplazarse hasta la opción Contraseña con los botones y y presionar el botón .

Escoger si el sistema pide o no pide la contraseña con los botones y y presionar el botón .

Escribir los cuatro números de la contraseña.

Escribir nuevamente los cuatro números de la contraseña.

Una vez establecida la contraseña el Reloj MA 32-2 la pedirá cada vez que se acceda al menú, en donde existe un tiempo limite de 5 segundos para poderla escribir. Si se desea desactivar la contraseña se escoge NO a la pregunta pedir contraseña en este menú.

Nota: Si olvida la contraseña de seguridad debe desconectar el equipo y retirar la pila interna CR2032 durante al menos 10 segundos, esto borrara la contraseña y la hora actual.

15

# 5 Conexión de los timbres

El Reloj MA 32-2 posee un conector de potencia el cual cierra el circuito cuando un timbrado es activado por una alarma o cuando se presiona la tecla #. Este contacto soporta una corriente máxima de 15A en 100 a 240 VAC (1800W/3600W) y está esta protegido con un fusible de 15A.

Los timbres se deben conectar en paralelo con una rama al Neutro (N) de la instalación eléctrica y la otra rama al conector de potencia del Reloj MA 32-2, el otro contacto del conector de potencia debe ser conectado a la Linea (L) de la instalación eléctrica. Es muy importante que la instalación eléctrica soporte la corriente requerida por los timbres. El esquema de la Figura 5.1 muestra de forma mas detallada la conexión.

Figura 5.1: Esquema de conexión de timbres

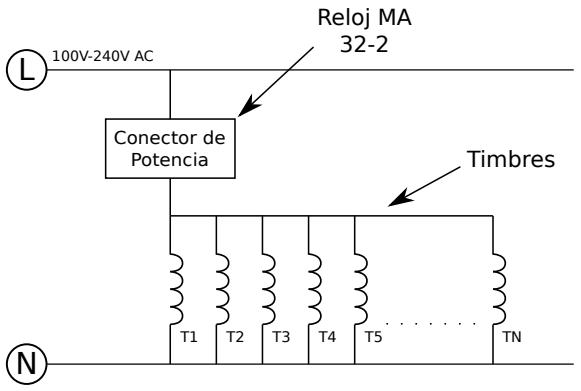
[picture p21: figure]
Reloj MA 32-2; Conector de; Potencia; Timbres

Es muy importante calcular y medir la corriente que demanda la instalación de timbres que se tenga antes de conectar el

16

Reloj MA 32-2, si la corriente demandada supera las características del Reloj MA 32-2 contacte a Galeras Digital para dar solución a sus nuevos requerimientos.

Nota: Galeras Digital no se hace responsable por daños causados debido a una instalación inadecuada o por fallas presentadas del fluido eléctrico.

17

# 6 Garantía

Este producto esta garantizado por Galeras Digital al comprador original de estar libre de defectos en los materiales y fabricación bajo uso normal por un periodo de un año de la fecha de compra. Durante el periodo de garantía y con la factura de compra; el producto será reparado utilizando piezas de remplazo originales y si es el caso el producto será remplazado en su totalidad. Para obtener el servicio de garantía usted debe contactar a Galeras Digital y poseer una copia de su factura de compra que muestre la fecha de tal compra, usted no tendrá cargo por las piezas o la reparación.

El cliente NO tendrá reclamo alguno bajo esta garantía para gastos de reparaciones o ajustes si:

### 1. El problema es causado por un trato incorrecto, maltrato

o descuido

2. Los sellos de garantía muestran señales de violación.

### 3. El problema es causado por un incendio u otro desastre

natural.

### 4. El problema es causado por la reparación o ajuste inade-

cuado realizado por personas que no pertenecen a Galeras Digital.

5. El periodo de garantía ha expirado.

18

## 6.1. Contactos

Para contactar a Galeras Digital puede comunicarse al siguiente celular, correo electrónico o pagina web:

Ventas y soporte técnico:

- Juan Pablo Ruiz: 301 323 4324

(Cajicá - Colombia)

Correo electrónico: galerasdigital@gmail.com

Pagina web:
http://www.galerasdigital.com

M/V: 3.03-30x4/01/10/14

F/V: 30x4-06/12

19

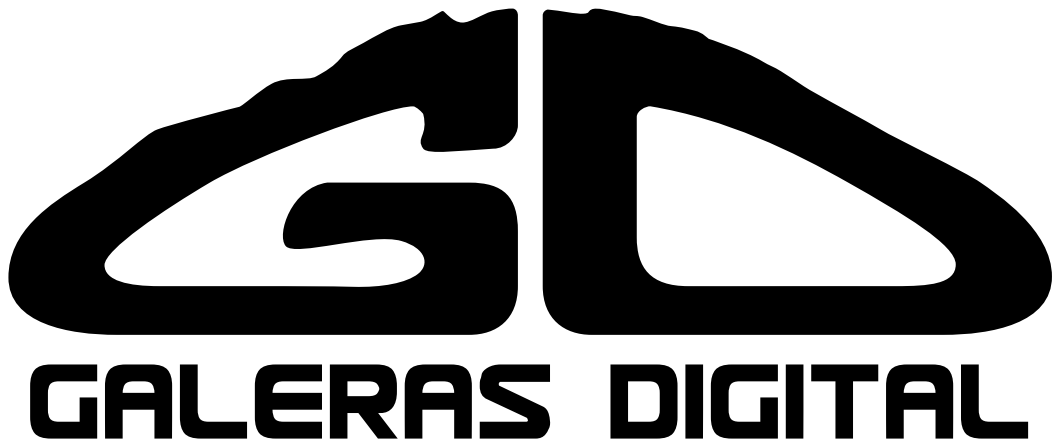
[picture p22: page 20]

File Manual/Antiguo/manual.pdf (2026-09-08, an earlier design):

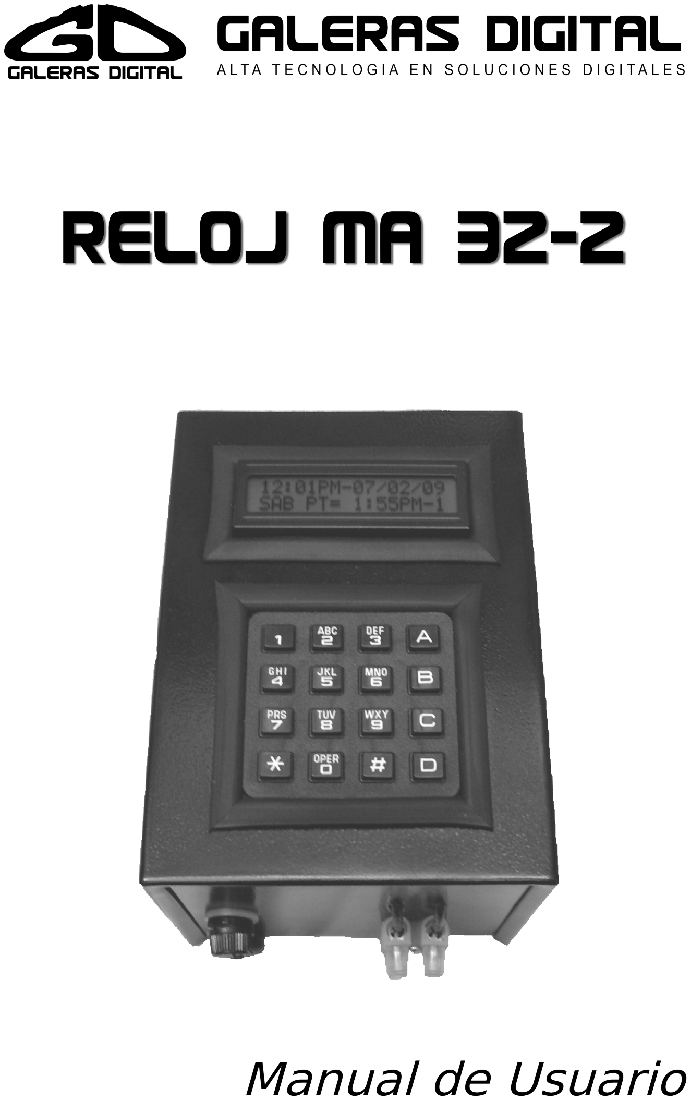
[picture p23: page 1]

# Índice general

1. Descripción General | 3
2. Fijar Reloj | 11
3. Fijar Alarmas | 12
4. Contraseña | 15
5. Conexión de los timbres | 16
6. Garantía | 18

# 1 Descripción General

El Reloj MA 32-2 en un dispositivo electrónico digital que cuenta con un reloj calendario y la posibilidad de programar 30 distintas alarmas con diferentes opciones de timbrado en cuatro diferentes tipos de horarios. Maneja un contacto de potencia capaz de soportar hasta 15A a 120VAC (1800W), una memoria interna tipo EEPROM donde se almacena la configuración de las alarmas sin perder los datos por hasta 40 años, una pila interna CR2032 para no perder la fecha y hora en caso de fallas del fluido eléctrico y un menú en pantalla LCD que facilita su manejo.

Ventajas:

La precisión en el timbre para el cambio de hora, es de gran importancia para toda la comunidad educativa, pero especialmente para el docente quien podrá programar sus actividades de clase con la plena seguridad de que el timbre de cambio de hora sonará con una precisión de segundos.

La labor diaria y constante del toque del timbre se olvidará por completo, ya que el Reloj MA 32-2 se programa por una sola vez y no requiere de ninguna otra operación.

## 1.1. Características

Cuatro Horarios: El Reloj MA 32-2 permite programar cuatro horarios distintos, cada uno hasta con 30 alarmas, los cuales se pueden asignar independientemente a los diferentes días de la semana.

Fácil Manejo: Su programación es muy sencilla y se realiza por una sola vez, esta no se borrará aunque se suspenda el fluido eléctrico.

Pila de respaldo: El Reloj MA 32-2 cuenta con una pila de respaldo la cual permite al sistema mantener la fecha y la hora en caso de cortes en el fluido eléctrico. La pila usada, CR2032 tiene una duración de 10 años.

Pantalla LCD: Su pantalla LCD retro iluminada, facilita la programación y muestra constantemente la hora exacta y la hora del próximo timbre.

Teclado Numérico: Su teclado numérico y de funciones permite una fácil programación de los timbrados y el cambio de horario.

Adaptabilidad: El Reloj MA 32-2 se instala y adapta fácilmente a cualquier sistema de timbre, chicharra o sistema de alarma.

Seguridad: El Reloj MA 32-2 posee un sistema de seguridad que solicita una clave o contraseña, para evitar que personas no autorizadas accedan o modifiquen la programación.

Calidad: El Reloj MA 32-2 está elaborado con materiales de altísima calidad lo que garantiza un funcionamiento preciso e ininterrumpido durante muchos años.

## 1.2. Vista frontal

En la parte frontal se encuentra una pantalla LCD y un teclado de números y funciones con los cuales se opera el Reloj MA 32-2.

Figura 1.1: Vista frontal

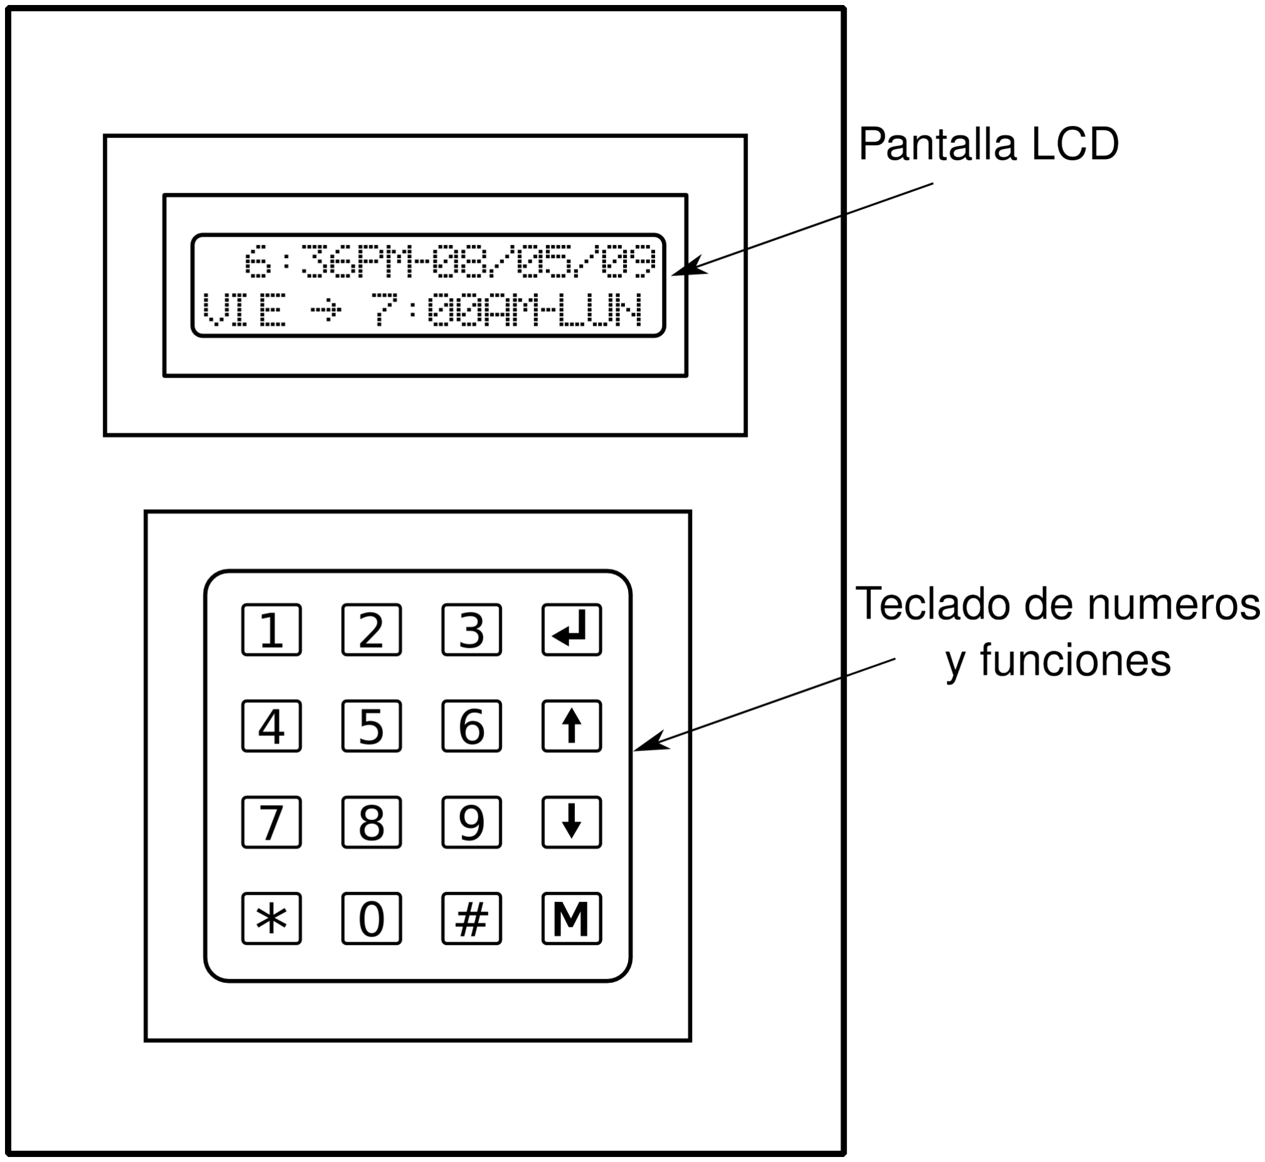
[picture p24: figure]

## 1.3. Vista inferior

En la parte inferior se encuentra la entrada de corriente, el fusible de potencia que protege el contacto interno y el conector de potencia donde se conecta el circuito de los timbres.

Figura 1.2: Vista inferior

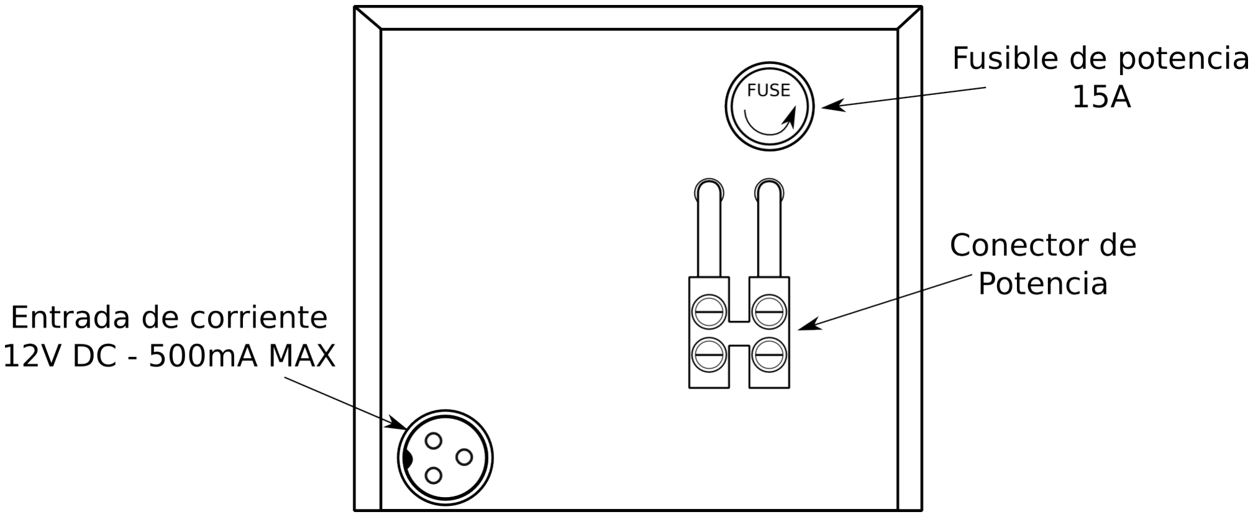
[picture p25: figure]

## 1.4. Vista superior

En la parte superior se encuentra un pulsador auxiliar de timbrado el cual cierra el contacto de potencia para realizar un timbrado que no halla sido programado. El interruptor de timbrado automático impide que el sistema cierre el contacto de potencia con el fin de desactivar los timbres.

Figura 1.3: Vista superior

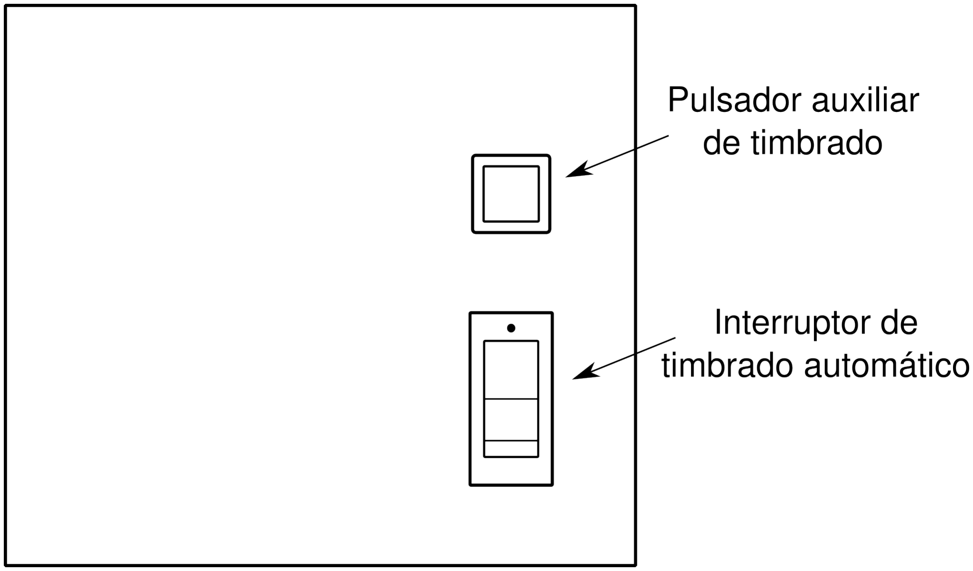
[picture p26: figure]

## 1.5. Pantalla principal

En la pantalla principal se muestra la hora actual en formato AM/PM, la fecha compuesta en su orden por el día del mes, el mes y los dos últimos dígitos del año, en la segunda linea se encuentra el día de la semana, seguido por una flecha y la hora y el día próximo timbrado.

Nota: Si no existe ninguna alarma programada en los tipos de horario o ningún tipo de horario esta asignado a algún día de la semana el espacio donde se encuentra la hora y el día del próximo timbrado aparecerá en blanco

Figura 1.4: Pantalla principal

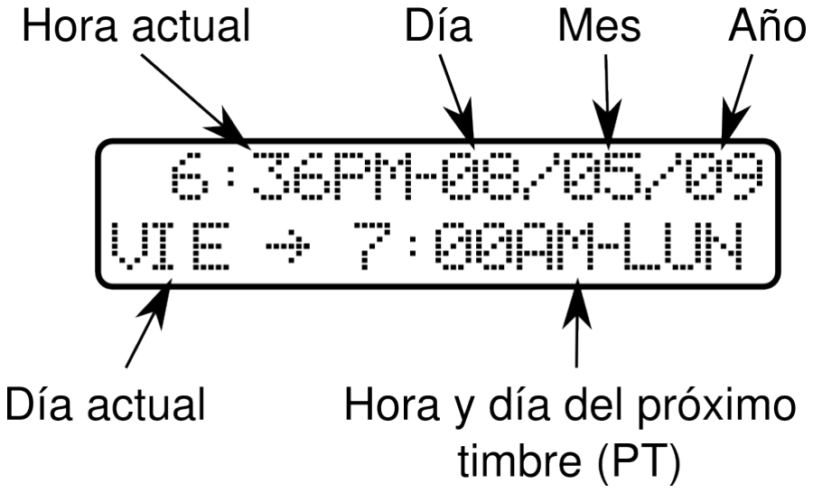
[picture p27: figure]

## 1.6. Teclado de números y funciones

Este teclado esta compuesto por una sección numérica y una sección de funciones. La tecla Enter ( ) para Aceptar, para acceder a un menú o validar un cambio. Las teclas y se usan como flechas arriba y abajo respectivamente para desplazarse entre el menú o diferentes opciones. Finalmente, la tecla se usa para acceder o salir del Menú de configuración. Cada vez que se accede al menú la luz de fondo de la pantalla LCD se activa, al salir del menú, permanece activa esta luz por 10 segundos. El botón asterisco (*) o de luz de fondo activa la luz por 10 segundos para poder visualizar los mensajes de la pantalla principal.

Figura 1.5: Teclado de números y funciones

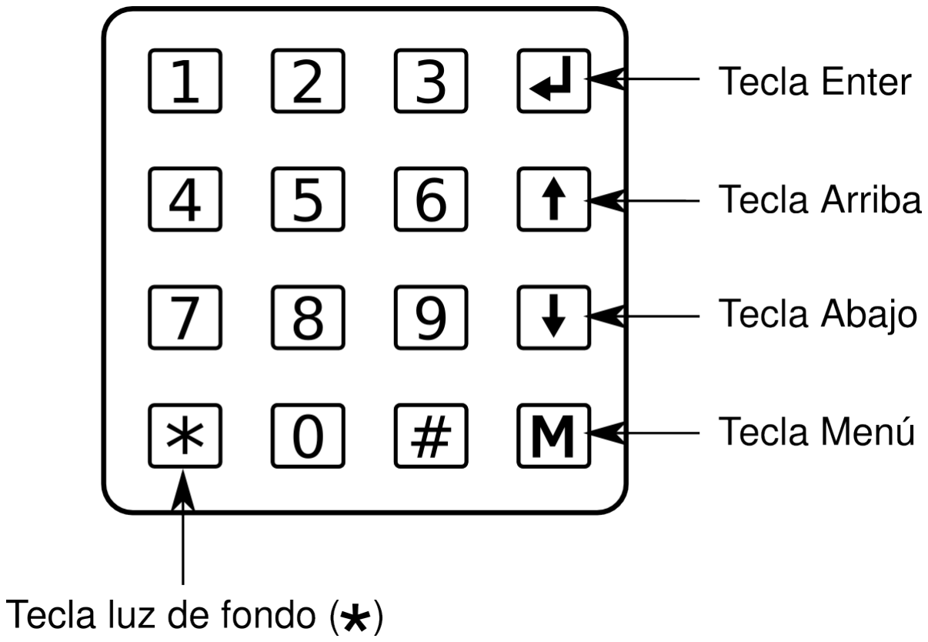
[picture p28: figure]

## 1.7. Menú de configuración

Con la tecla , se accede al menú de configuración en el cual el usuario puede desplazarse por las diferentes opciones con la ayuda de las teclas y , para acceder a la opción deseada se pulsa la tecla . El menú esta compuesto de las siguientes opciones que se describen en los capítulos posteriores.

Fijar Reloj

Fijar Alarmas

Tipo de Horario

Contraseña

Dura. Timbres

## 1.8. Interruptor de timbrado automático

El interruptor de timbrado automático impide que el sistema cierre el contacto de potencia lo cual desactiva el timbrado automático programado, esto función ayuda a desactivar los timbres cuando el usuario lo desee por ejemplo en días feriados. El estado de encendido de este interruptor se distingue cuando este esta posicionado del lado del punto blanco.

Nota: Se recomienda colocar el Interruptor de timbrado automático en apagado al momento de conectar a la corriente eléctrica el Reloj MA 32-2 para evitar timbrados no deseados

# 2 Fijar Reloj

La opción Fijar Reloj permite ajustar la hora y la fecha actual, para ello se procede de la siguiente forma:

Acceder al menú con el botón .

Desplazarse hasta la opción Fijar Reloj con los botones y y pulsar el botón .

Establecer la hora y los minutos con la ayuda de el teclado numérico.

Fijar AM o PM con la ayuda de las teclas | y | y luego
pulsar el botón .

Fijar el día, el mes y los dos últimos dígitos del año con el teclado numérico.

Fijar el día de la semana con las teclas y y pulsar finalmente el botón .

Una vez pulsado el botón después de fijar el día de la semana la hora queda establecida y los segundos se reinician a cero. El Reloj MA 32-2 cuenta con una pila interna CR2032 la cual es capaz de almacenar la hora en caso de fallas de energía por hasta 10 años. Si al momento de el restablecimiento de la energía la hora no es la correcta es necesario cambiar esta pila.

# 3 Fijar Alarmas

La opción Fijar Alarmas permite ajustar las 30 alarmas dentro de cada uno de los 4 tipos de horario. Primero se escoge el tipo de horario a modificar con la ayuda de las teclas y , se lo selecciona con el botón , luego la pantalla muestra la Figura 3.1 que indica el numero de la alarma, el tipo de horario al que pertenece, la hora a la que esta fijada esta alarma el tipo de timbrado y el estado de la alarma, apagada (OFF) o encendida (ON).

Figura 3.1: Pantalla fijar alarmas

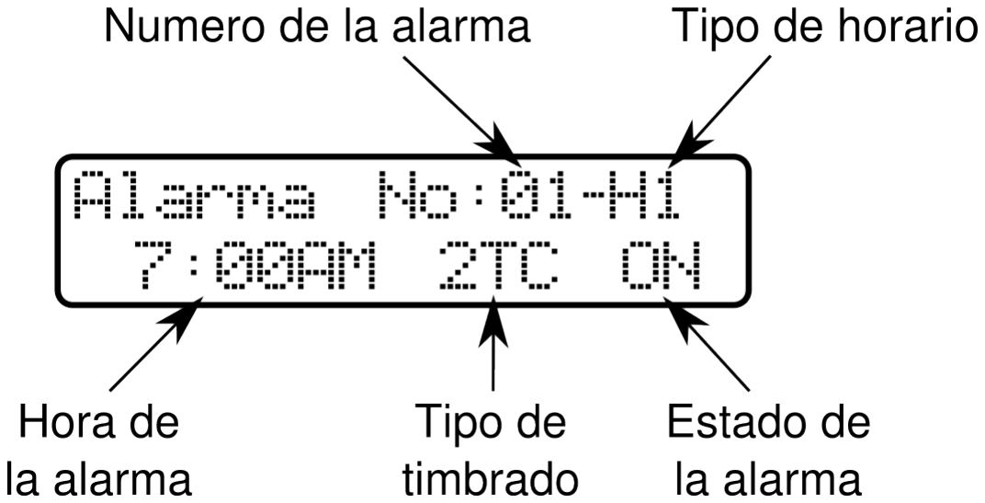
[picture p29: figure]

Para desplazarse entre las alarmas se usan los botones | y ,
para fijar una alarma se pulsa el botón | estando en el numero
de alarma que se desea modificar y se sigue este orden:

Establecer la hora y los minutos de la alarma con la ayuda de el teclado numérico

Fijar AM o PM con la ayuda de las teclas | y | y luego
pulsar el botón

Fijar el tipo de timbrado con las teclas y y luego pulsar el botón

Fijar el estado de la alarma con las teclas y en encendida (ON) o apagada (OFF) y finalmente pulsar el botón

De esta misma forma se pueden fijar una o todas las alarmas. Cada vez que se configura una alarma estos datos quedan guardados en la memoria EEPROM del sistema lo que evita pérdida de los datos en caso de fallo de la energía.

Nota: No es necesario colocar las alarmas en orden

## 3.1. Tipo de timbrado

El Reloj MA 32-2 soporta 4 diferentes modos de timbrado que son los siguientes:

1TC: 1 Timbre corto

1TL: 1 Timbre largo

2TC: 2 Timbres cortos

3TC: 3 Timbres cortos

La duración de los intervalos de tiempo de los timbres se establecen con el menú Dura. Timbres que se explica a continuación.

## 3.2. Dura. Timbres

En el menú Dura. Timbres se establece la duración del timbre corto y del timbre largo, de la siguiente forma:

Acceder al menú con el botón

Desplazarse hasta la opción Dura. Timbres con los botones y y pulsar el botón .

Establecer con los botones y la duración en segundos del timbre corto (TC) y pulsar el botón .

Establecer con los botones y la duración en segundos del timbre largo (TL) y pulsar finalmente el botón .

## 3.3. Tipo de horario

El menú tipo de horario permite asignar el tipo de horario a cada día de la semana, asignando uno de los cuatro tipos de horario o ningún horario con la opción OFF, para configurar se procede de la siguiente forma:

Acceder al menú con el botón

Desplazarse hasta la opción Tipo de Horario con los botones y y pulsar el botón .

Escoger el día que se desea modificar con los botones y y pulsar el botón .

Seleccionar el tipo de horario con los botones | y y pul-
sar el botón | para guardar.
Pulsar el botón | para salir.

# 4 Contraseña

El Reloj MA 32-2 tiene la opción de proteger su configuración mediante una contraseña de 4 números, para proteger el sistema con una contraseña se procede de la siguiente forma:

Acceder al menú con el botón .

Desplazarse hasta la opción Contraseña con los botones y y pulsar el botón

Escoger si el sistema pide o no pide la contraseña con los botones y y pulsar el botón

Escribir los cuatro números de la contraseña

Escribir nuevamente los cuatro números de la contraseña

Una vez establecida la contraseña el Reloj MA 32-2 la pedirá cada vez que se acceda al menú, en donde existe un tiempo limite de 5 segundos para poderla escribir. Si se desea desactivar la contraseña se escoge NO a la pregunta pedir contraseña en este menú.

Nota: Si olvida la contraseña de seguridad debe desconectar el equipo y retirar la pila interna CR2032 durante al menos 10 segundos, esto borrara la contraseña y la hora actual.

# 5 Conexión de los timbres

El Reloj MA 32-2 posee un conector de potencia el cual cierra el circuito cuando un timbrado es activado por una alarma o cuando se oprime el pulsador auxiliar. Este contacto soporta una corriente máxima de 15A en 100 a 240 VAC (1800W/3600W) este esta protegido por el fusible de potencia de 15A.

Los timbres se deben conectar en paralelo con una rama al Neutro (N) de la instalación eléctrica y la otra rama al conector de potencia del Reloj MA 32-2, el otro contacto del conector de potencia debe ser conectado a la Linea (L) de la instalación eléctrica. Es muy importante que la instalación eléctrica soporte la corriente requerida por los timbres. El esquema de la Figura 5.1 muestra de forma mas detallada la conexión.

Figura 5.1: Esquema de conexión de timbres

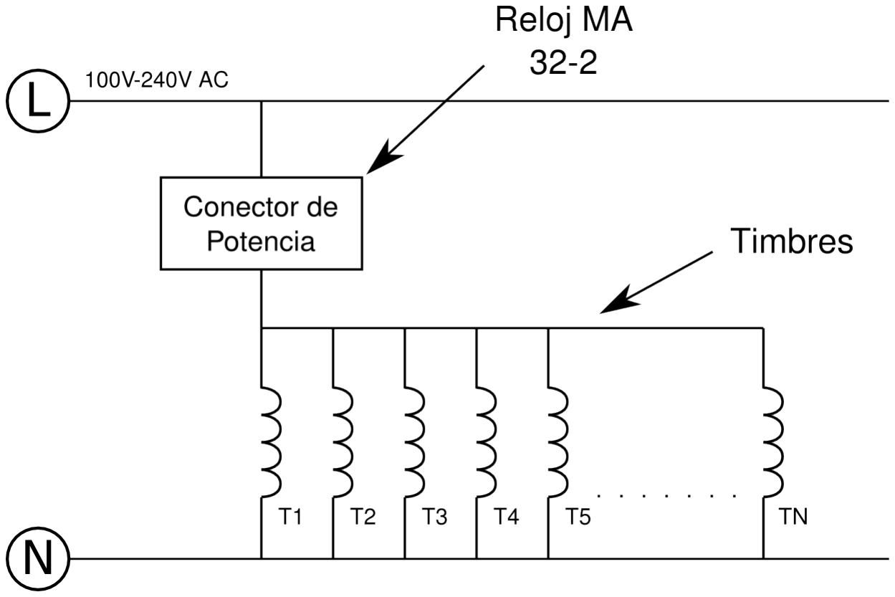
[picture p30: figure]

Es muy importante calcular y medir la corriente que demanda la instalación de timbres que se tenga antes de conectar el

Reloj MA 32-2, si la corriente demandada supera las características del Reloj MA 32-2 contacte a Galeras Digital para dar solución a sus nuevos requerimientos.

Nota: Galeras Digital no se hace responsable por daños causados debido a una instalación inadecuada o por fallas presentadas del fluido eléctrico

# 6 Garantía

Este producto esta garantizado por Galeras Digital al comprador original de estar libre de defectos en los materiales y fabricación bajo uso normal por un periodo de un año de la fecha de compra. Durante el periodo de garantía y con la factura de compra; el producto será reparado utilizando piezas de remplazo originales y si es el caso el producto será remplazado en su totalidad. Para obtener el servicio de garantía usted debe contactar a Galeras Digital y poseer una copia de su factura de compra que muestre la fecha de tal compra, usted no tendrá cargo por las piezas o la reparación.

El cliente NO tendrá reclamo alguno bajo esta garantía para gastos de reparaciones o ajustes si:

1. El problema es causado por un trato incorrecto, maltrato o descuido
2. Los sellos de garantía muestran señas de violación.
3. El problema es causado por un incendio u otra desgracia natural
4. El problema es causado por la reparación o ajuste inadecuado realizado por personas que no pertenecen a Galeras Digital
5. El contrato de compra no se presenta cuando se solicita el servicio.
6. El periodo de garantía ha expirado

## 6.1. Contactos

Para contactar a Galeras Digital puede comunicarse al siguiente celular, correo electrónico o pagina web:

Ventas y soporte técnico:

- Juan Pablo Ruiz: 301 323 43 24

Dirección: Carrera 24 # 4 Sur - 61 B/Mijitayo

(Pasto - Colombia)

Correo electrónico: galerasdigital@gmail.com

Pagina web: https://sites.google.com/site/galerasdigital

M/V: 2.02-30x4/12/06/12

F/V: 30x4-07/10

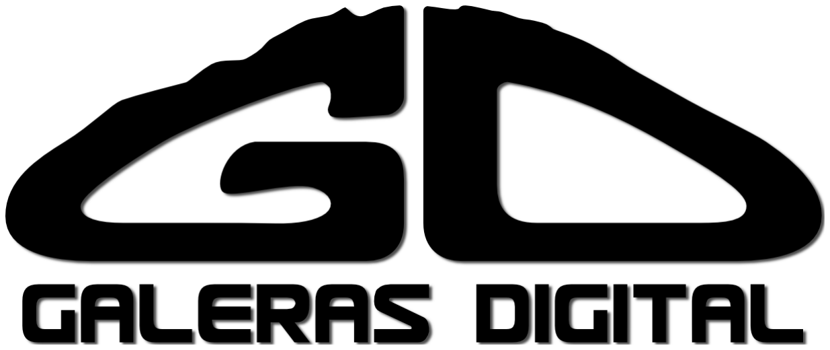
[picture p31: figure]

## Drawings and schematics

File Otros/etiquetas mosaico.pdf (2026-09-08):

# reloj mA 32-2

# reloj mA 32-2

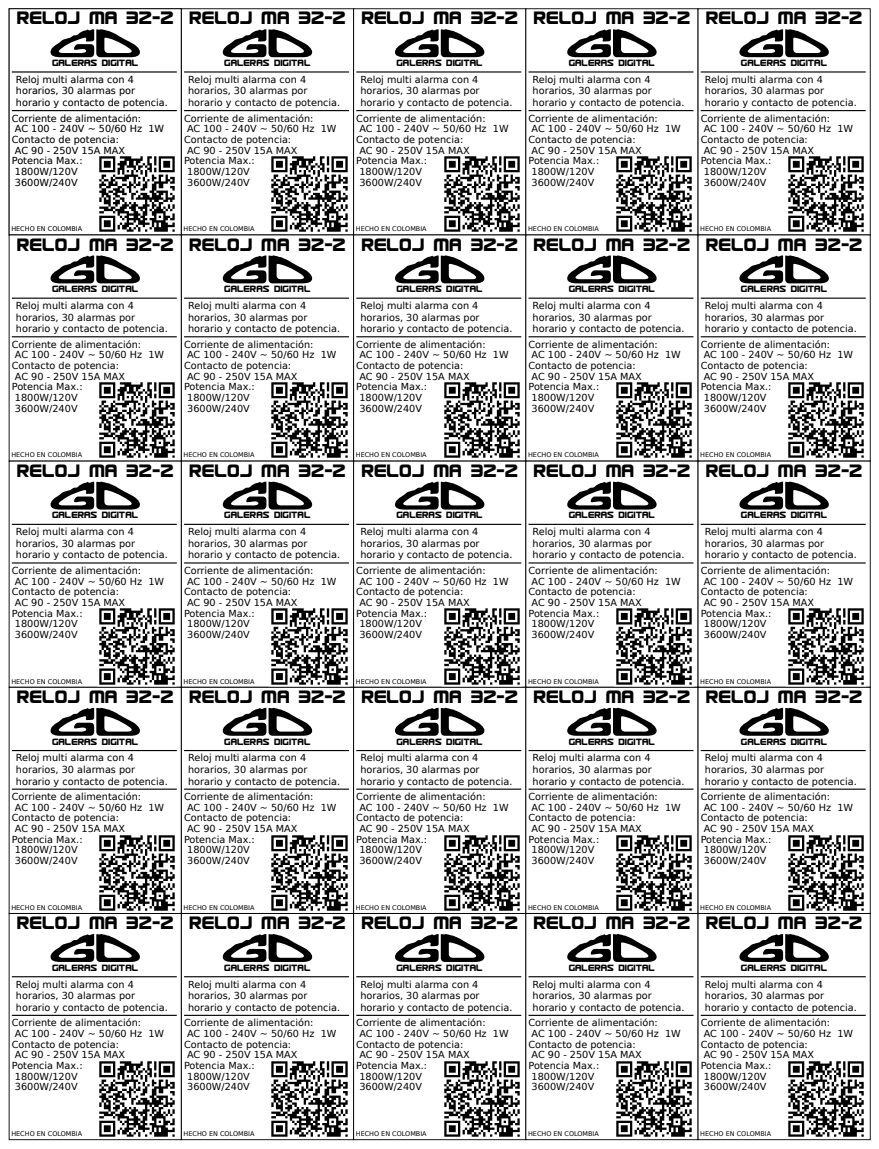
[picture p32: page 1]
GALERAS DIGITAL; reloj mA 32-2

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

HECHO EN COLOMBIA
reloj mA 32-2

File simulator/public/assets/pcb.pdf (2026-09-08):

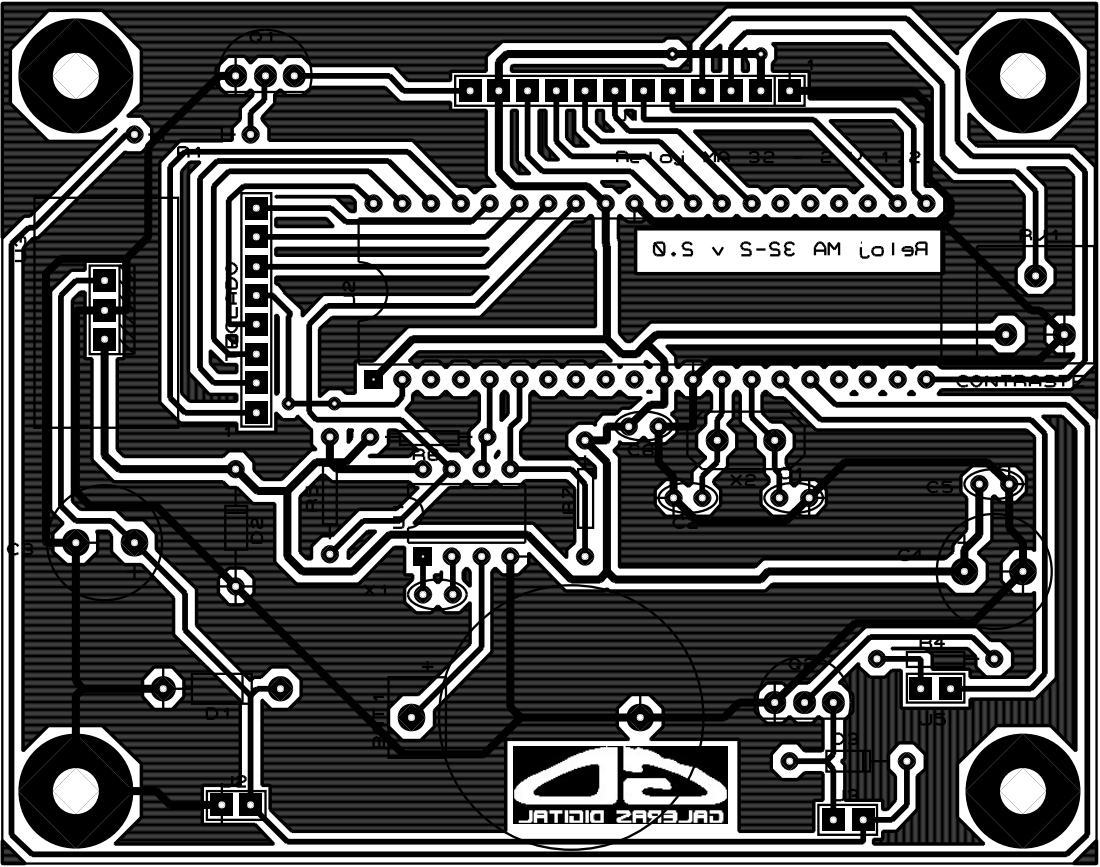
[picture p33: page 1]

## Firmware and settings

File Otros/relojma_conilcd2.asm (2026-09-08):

;**************************************** relojma.asm *****************************************************


; ZONA DE DATOS *******************************************************************************************

								
	__CONFIG _CP_ALL & _WDT_ON & _BODEN_ON & _PWRTE_ON & _XT_OSC & _LVP_OFF & _CPD_OFF
	; Configuración del microcontrolador

	LIST	 P=16F877A		; Procesador utilizado.
	INCLUDE  <P16F877A.INC>		; En este fichero se definen las etiquetas del PIC.

	CBLOCK	0x20
	NMENU
	DATOTECLA
	TEMPS
	TEMPW
	AMPM
	NALARMA
	NALARMAP
	CONTADOR
	HORAALARMA
	MINUTOALARMA
	DIAALARMA
	VTIPOHORARIO
	VTIPOHORARIO2
	ESTADOALARMA
	TIPOTIMBRE
	TEMPROTAR
	CONTROTAR
	NALARMACERCANA
	NALARMACERCANAF
	HORADIF
	MINUTODIF
	HORADIFMENOR
	MINUTODIFMENOR
	MINUTOMENOR
	CONTLEDLCD
	TEMPHORA
	PASSWA
	PASSWB
	PASSWA1
	PASSWB1
	CONTTECLADOWW
	ESTADOCONTRASENA
	DTIMBREC
	DTIMBREL
	SONADAALARMAMF
	MENDIAV
	CONTDIATH
	ULTIMAALARMAD
	TOTALADIAS
	CONTILCD
	BANDILCD
	ENDC
	
TARRIBA	EQU	0x0E
TABAJO	EQU	0x0D
TENTER	EQU	0x0F
TMENU	EQU	0x0C


#DEFINE  PINTIMBRE	PORTC,0			; Timbre por el puerto C bit 0 pin 15 
#DEFINE  PINLEDLCD	PORTC,1			; Pin para la luz de fondo del LCD
#DEFINE	 TIEMPOLCD	d'20'			; Define el tiempo en n*500ms de la duración
						; de la luz del LCD
#DEFINE  TCONTILCD	d'10'			; Define el tiempo en n*500ms de la nueva inicializacion LCD

#DEFINE  EEDDCONH	0xFE			; Direcciones donde se almacena la contraseña
#DEFINE  EEDDCONB	0xFF
#DEFINE	 EEDDESTACON	0xFD			; Dirección del estado de la contraseña
#DEFINE  EEDDTIMBREC	0xFB			; Direcciones en la EPROM para la duracion de timbres
#DEFINE  EEDDTIMBREL	0xFC
#DEFINE  EEDDTHLUN	0xF1			; El día lunes esta en la dirección F2 porque Lunes es 1 + F1
						; Domingo en la dirección F8, días de F2-F8


; ZONA DE CÓDIGOS ******************************************************************************************

	ORG 	0
  	GOTO	INICIO
	ORG	4
	GOTO	INTERRPUCION

	INCLUDE "D:\Electronica\RelojMA\Librerias\TECLADO.INC"


INICIO
;	MOVLW	0x18
;	MOVWF	Hora
;	MOVLW	0x32
;	MOVWF	Minuto
;	MOVLW	0x02
;	MOVWF	DiaSemana
	CALL	LCD_Inicializa		; Inicializa la pantalla y graba el logo en su memoria
	BSF	BANDILCD,0		; Inicializa la bandera de ILCD en 1 para decir que no se ha
					; dado la segunda inicialización
	MOVLW	TCONTILCD		; Inicializa el contador del tiempo del LCD
	MOVWF	CONTILCD	
	BSF 	PCLATH,3 		; Pagina 1
	BCF 	PCLATH,4 
	CALL	COMPALARMAS	
	CLRF	PCLATH			; Pagina 0
	
	BCF	PINTIMBRE		; Se asegura que el timbre esta apagado		
	CALL	Teclado_Inicializa	; Configura las líneas del teclado.

	BSF	STATUS,RP0		; Pone a 1 el bit 5 del STATUS. Acceso al Banco 1.
	MOVLW	0x07			; Todas las entradas digitales
	MOVWF	ADCON1
	BSF	OPTION_REG,INTEDG	; Interrupción INT de RB0 activada por flanco de bajada.
	BSF	OPTION_REG,PSA		; Preescaler asignado al WDT
	BSF	OPTION_REG,PS0		; Preescaler en 1:128 x 18ms
	BSF	OPTION_REG,PS1
	BSF	OPTION_REG,PS2
	BSF	PORTB,0			; Coloca al RB0 como entrada
	BCF	PORTA,1
	BCF	PINTIMBRE		; Coloca al pin del timbre como salida
	BCF	PINLEDLCD		; Coloca el pin de la luz de fondo del LCD como salida
	BCF	STATUS,RP0
	CALL	DS1307_Inicializa

	CALL	DS1307_Lee		; Lee los segundos en el DS1307 y comprueba el
	BTFSS	Segundo,7		; valor del bit CH. Si es "1" salta toda la
	GOTO	INICIO2			; inicialización de los registros y la puesta
					; en hora inicial.
	call	DS1307_CargaInicial	; Realiza la carga inicial 
	MOVLW	EEDDESTACON		; Dirección de estado de la contraseña
	CALL	EEDIR
	CLRW				; Cuando se quita la pila
	CALL	EEESCRIBIR		; Deshabilita la contraseña
	


INICIO2
	BSF	PINLEDLCD
	BSF 	PCLATH,3 		; Pagina 1
	BCF 	PCLATH,4 
	CALL	COMPALARMAS	
	CLRF	PCLATH			; Pagina 0
	CALL	ARELOJ

	MOVLW	b'10011000'		; Habilita la interrupción INT de RB0, RBI y la general.
	MOVWF	INTCON
	BCF	PINTIMBRE		
	MOVLW	TIEMPOLCD
	MOVWF	CONTLEDLCD
	CLRF	SONADAALARMAMF


PRINCIPAL
	SLEEP
	GOTO	PRINCIPAL


; ZONA DE INTERRUPCION ***************************************************************************************	
INTERRPUCION
	MOVWF	TEMPW
	SWAPF	STATUS,W
	MOVWF	TEMPS

	BTFSC	INTCON,INTF		; Interrupción del reloj
	CALL	ARELOJ
	BTFSC	INTCON,INTF		; Interrupción del reloj
	CALL	TESTEARALARMA

	BTFSC	INTCON,RBIF		; Interrupción del teclado
	GOTO	ITECLADO

FININTERRUPCION
	SWAPF	TEMPS,W			; Devuelve las variableds
	MOVWF	STATUS
	SWAPF	TEMPW,F
	SWAPF	TEMPW,W

	BCF	INTCON,RBIF		; Resetea las banderas de interrupción
	BCF	INTCON,INTF
	RETFIE


; ZONA DE SUBRUTINAS ***************************************************************************************
LCD_Inicializa2
	CALL	LCD_Inicializa
	CALL	LCD_Inicializa
	BCF	BANDILCD,0		; Ya inicializado se coloca esta bandera en cero.
;	CALL	Retardo_100ms
;	BSF	PINTIMBRE
;	CALL	Retardo_200ms
;	BCF	PINTIMBRE

	RETURN

; INTERRUPCIÓN POR TECLADO **********************************************************************************
ITECLADO
	CALL	LCD_Inicializa
	BSF	PINLEDLCD			; Enciende la luz de fondo del LCD
	MOVLW	TIEMPOLCD			; Inicilaliza el contador de luz LCD
	MOVWF	CONTLEDLCD
	CALL	Teclado_LeeHex			; Obtiene el valor hexadecimal de la tecla pulsada.
	SUBLW	TMENU
	BTFSS	STATUS,Z
	GOTO	FINITECLADO

	CALL	Teclado_EsperaDejePulsar	; Para que no se repita el mismo carácter 

	MOVLW	EEDDESTACON				; Comprueba si el sistema piede o no contraseña
	CALL	EEDIR
	CALL	EELEER
	MOVWF	ESTADOCONTRASENA
	BTFSS	ESTADOCONTRASENA,0
	GOTO	ITECLADO1

	CALL	LCD_Borra			; Pide la contraseña
	CALL	MCONTRASENA
	CALL	LCD_Linea2
	MOVLW	0xFF
	MOVWF	CONTTECLADOWW

	CALL	Teclado_LeeHexww
	MOVWF	PASSWA
	SWAPF	PASSWA,F
	MOVLW	'*'
	CALL	LCD_Caracter
	CALL	Teclado_LeeHexww
	ADDWF	PASSWA,F
	MOVLW	'*'
	CALL	LCD_Caracter

	CALL	Teclado_LeeHexww
	MOVWF	PASSWB
	SWAPF	PASSWB,F
	MOVLW	'*'
	CALL	LCD_Caracter
	CALL	Teclado_LeeHexww
	ADDWF	PASSWB,F
	MOVLW	'*'
	CALL	LCD_Caracter
	
	MOVLW	EEDDCONH				; Comprueba la contraseña
	CALL	EEDIR
	CALL	EELEER
	SUBWF	PASSWA,W
	BTFSS	STATUS,Z
	GOTO	FINITECLADO			; Contraseña invalida

	MOVLW	EEDDCONB
	CALL	EEDIR
	CALL	EELEER
	SUBWF	PASSWB,W
	BTFSS	STATUS,Z
	GOTO	FINITECLADO			; Contraseña invalida

ITECLADO1					
	
	CALL	LCD_Borra			; Borra y muestra el menu
	MOVLW	'M'
	CALL	LCD_Caracter
	MOVLW	'E'
	CALL	LCD_Caracter
	MOVLW	'N'
	CALL	LCD_Caracter
	MOVLW	'U'
	CALL	LCD_Caracter

	MOVLW	d'10'
	CALL	LCD_PosicionLinea1

	MOVLW	0x00			; Imprime los caracteres que conforman el logo
	CALL	LCD_Caracter
	MOVLW	0x01
	CALL	LCD_Caracter
	MOVLW	0x02
	CALL	LCD_Caracter
	MOVLW	0x03
	CALL	LCD_Caracter
	MOVLW	0x04
	CALL	LCD_Caracter
	MOVLW	0x05
	CALL	LCD_Caracter

	CLRF	NMENU
	CALL	ACTMENU

ITECLADO2	
	CALL	Teclado_LeeHexw
	MOVWF	DATOTECLA
	SUBLW	TABAJO
	BTFSC	STATUS,Z
	CALL	INCNMENU
	
	MOVF	DATOTECLA,W
	SUBLW	TARRIBA
	BTFSC	STATUS,Z
	CALL	DECNMENU
	
	MOVF	DATOTECLA,W
	SUBLW	TMENU
	BTFSC	STATUS,Z
	GOTO	FINITECLADO
	
	MOVF	DATOTECLA,W
	SUBLW	TENTER
	BTFSC	STATUS,Z
	GOTO	ENTERMENU

	CALL	ACTMENU

	CALL	Teclado_EsperaDejePulsar	; Para que no se repita el mismo carácter 
 	GOTO	ITECLADO2
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
